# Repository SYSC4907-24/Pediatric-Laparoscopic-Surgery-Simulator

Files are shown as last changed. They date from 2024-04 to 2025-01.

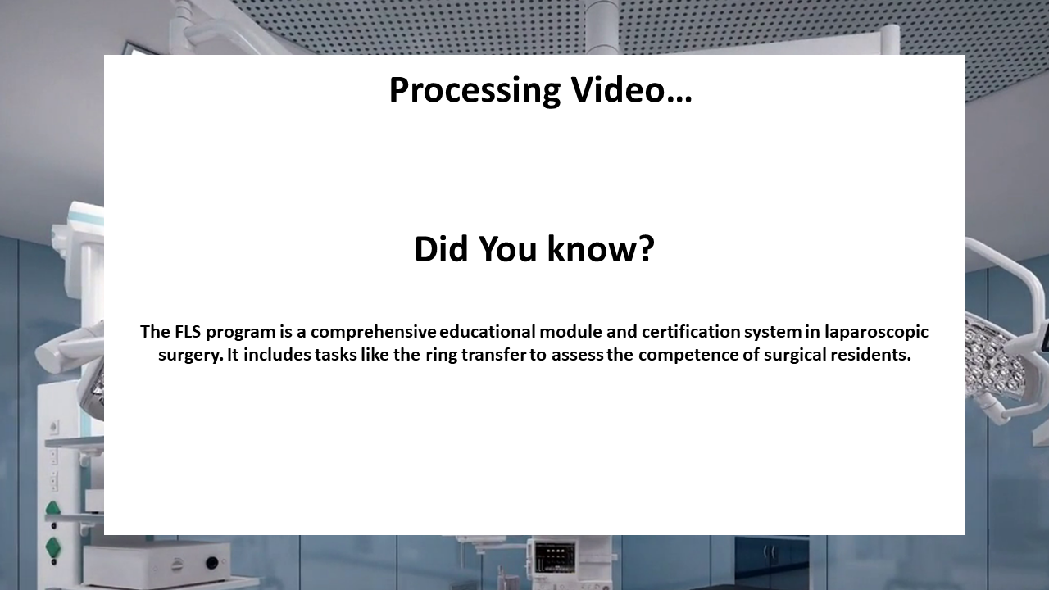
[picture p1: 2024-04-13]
Software/Slide8.PNG

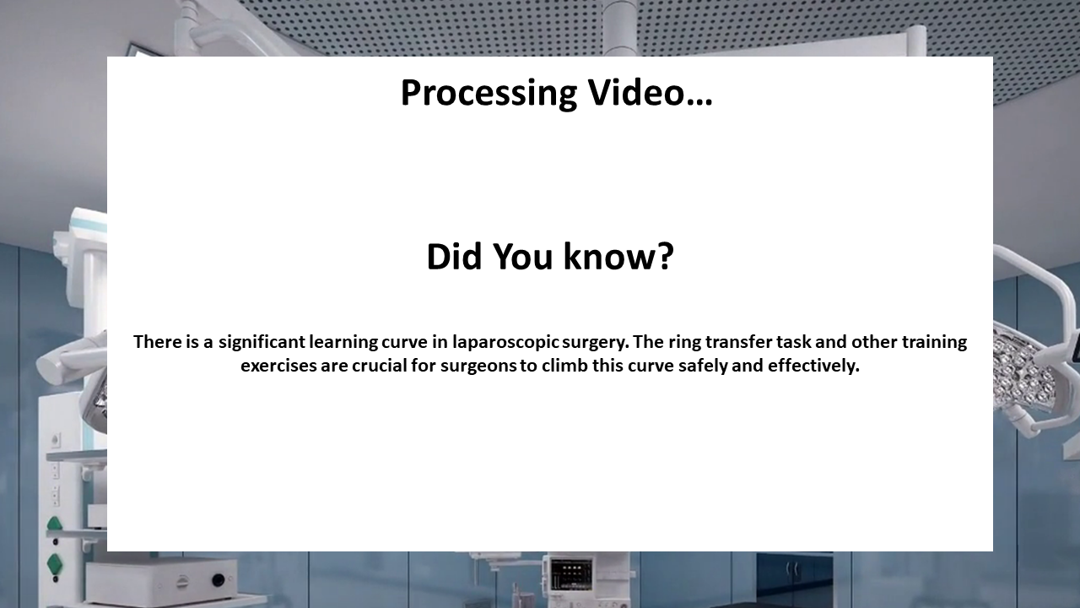
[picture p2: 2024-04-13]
Software/Slide6.PNG

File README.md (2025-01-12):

# Development of a Pediatric Laparoscopic Training and Skills Assessment Simulator 
*Source Repository for Systems and Computer Engineering Capstone Poject 2023 - 2024 at Carleton University.*

## Features
This project is a simulation designed for pediatric laparoscopic surgery training. The software simulates various surgical tasks, such as ring and suturing tasks. It captures video input, processes the data, and provides real-time feedback based on sensor data.

## Installation
### Requirements
* [Python 3](https://www.python.org/) (Tested on 3.7, 3.8)
* [Arduino](https://www.arduino.cc/en/software)
  * Set the loader to oldboot.

### Run Locally
Clone the project:
```bash 
  git clone https://github.com/SYSC4907-24/Pediatric-Laparoscopic-Surgery-Simulator.git
```
Install Python packages:
```bash
python -m pip install -r requirements.txt
```

Execute the `main.py` file:
```bash
python main.py
```

## Authors  
- Atallah Madi  
- Esraa Alaa Aldeen  
- Huda Sheikh 
- Youssef Megahed

If you have any feedback, please reach out to us.

Edit date: April 25, 2024.

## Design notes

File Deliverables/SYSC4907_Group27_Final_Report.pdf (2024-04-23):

Final Report

# Development of a Pediatric Laparoscopic

# Training and Skills Assessment Simulator

Authors:

Atallah Madi

Esraa Alaa Aldeen

Huda Sheikh

Youssef Megahed

Group 27

(Biomedical and Electrical Engineering)

Supervised by:

Dr. Carlos Rossa

Report Date:
April 10th, 2024

SYSC 4907

Department of Systems and Computer Engineering

Faculty of Engineering and Design

Carleton University

Final Report | Group Number: 27

II

Abstract

Pediatric laparoscopic surgery is a minimally invasive technique used for training trainees

on basic surgical movements while providing them with comprehensive feedback. The simulator

incorporates advanced technologies such as augmented reality (AR), sensor technology, signal

processing, and machine learning to provide an efficient learning experience that mimics a

complex pediatric laparoscopic environment. It addresses challenges such as operating in 3D while

viewing in 2D, enhancing learning, and eliminating expert supervision. This simulator's unique

features include real-time feedback and performance assessment through Dynamic Time Warping

(DTW) and deep learning, allowing for comparison with expert surgeons. The simulator is

designed to be user-friendly, with an intuitive UI and data processing pipeline, making surgical

training more accessible and efficient.

Keywords: Pediatric Laparoscopic, Simulator, Augmented Reality, Machine Learning, Deep

Learning, Surgical Gestures, Instrumentation, Feedback.

III

Acknowledgements

Group 27, comprising Atallah Madi, Esraa Alaa Aldeen, Huda Sheikh, and Youssef

Megahed would like to extend our sincere thanks to Dr. Carlos Rossa for his invaluable

mentorship, and remarkable support throughout our capstone project. We would also like to

acknowledge Dr. James Green for his constructive advice and practical suggestions, Dr. Ahmed

Nasr from C.H.E.O, and Dr. Georges Azzie from SickKids for their medical insights prior to our

development of the Pediatric Laparoscopic Surgery Simulator.

We would also like to express our appreciation to Carleton University for publishing an

article featuring our project, Biomechatronic Lab for providing us with the necessary tools and

working environment, the Systems and Computer Engineering Department and Kostiuk

Engineering Funding Collective for their generous funding, which made this project possible.

All these individuals and organizations have been instrumental in our project's success, and

we are deeply thankful for everyone and their contributions.

IV

Table of Contents

ABSTRACT | II
ACKNOWLEDGEMENTS | III
TABLE OF CONTENTS | IV
TABLE OF FIGURES | V
LIST OF TABLES | VII

V

Table of Figures

FIGURE 2: PEDIATRIC LAPAROSCOPIC SURGERY SETUP WITH A LAPAROSCOPE AND INSTRUMENTS INSERTED THROUGH TROCARS

FIGURE 3: LAPAROSCOPIC INSTRUMENTS COMMONLY USED TODAY. FROM LEFT TO RIGHT, LAPAROSCOPE (TOP LEFT), NEEDLE

FIGURE 4:THE FOUR DEGREES OF MOTION SURGEONS ARE LIMITED TO IN LAPAROSCOPY ARE THE ROLL, PITCH, YAW, AND SURGE

FIGURE 10:(A): ILLUSTRATION OF THE REFLECTION AND IMAGING SENSOR.(B): WORKING PRINCIPLE OF THE OPTICAL SENSOR

FIGURE 21: COMPARATIVE ANALYSIS OF AUTOMATED ACCURATE GESTURE DETECTION: SSD MOBILENET V2 320X320 VS.

FIGURE 22: COMPARATIVE OF AUTOMATED ACCURATE GESTURE DETECTION ON THE RIGHT (IMAGE C) AND INACCURATE ON

FIGURE 37: SAMPLE PROTOTYPE FOR OUR USER INTERFACE SHOWING VARIOUS MENU SCREENS (TOP) AND LOADING SCREENS

FIGURE 38: DESIGN FLOW OF NEW USER INTERFACE SHOWN WITH WINDOWS/SCREENS THAT APPEAR WHEN CERTAIN BUTTONS

VI

FIGURE 47: YAW (DEGREES) VS TIME (SECONDS) TEST WITH MPU INSIDE SENSOR HOUSING ON BOX [23] | 74
FIGURE 48: ROLL (DEGREE) VS TIME (SECONDS) TEST DONE WITH THE TOOL SHAFT INSIDE THE SENSOR HOUSING[23] | 75
FIGURE 49: SURGE (MM) VS TIME (SECONDS) WITH THE TOOL SHAFT INSIDE THE SENSOR HOUSING [23] | 75

VII

List of Tables

### 1. Introduction

This report provides a final update on our capstone project, a state-of-the-art Pediatric

Laparoscopic Surgery Simulator. This simulator, which incorporates advanced augmented reality

technology with machine learning, aims to provide enhanced feedback for performance evaluation.

Along with improved evaluation schemes, users are immersed in an interactive, risk-free training

environment that verbally and visually guides them throughout their learning experience. From

previous iterations, we have now integrated our machine-learning-driven object detection for

surgical tasks to be used for performance evaluation in real-time as the user interacts with the user

interface. We have also improved the hardware configuration of the simulator, equipping it with a

computer and display screen to ensure it is a compact, portable device that can be utilized in various

settings. Finally, significant improvements were made to enhance the user’s experience while

interacting with the user interface and viewing their feedback after performing a surgical task. The

changes implemented in this iteration will be detailed in the sections below. This report begins

with an overview of the project's primary goal, emphasizing the critical need for innovative

training tools in this specialized field of laparoscopic surgery. We then offer in-depth background

information crucial to understanding the project and the work we have accomplished this year.

This includes an overview of pediatric laparoscopic surgery, the current standards and

requirements for pediatric laparoscopic surgical training, and an analysis of recent technological

advancements in simulation tools that enhance the skill set of surgeons. In the following section,

we delve into the relevance of this project to the academic pursuits of each team member within

the fields of Biomedical and Electrical Engineering, outlining the specific responsibilities and roles

undertaken by each member during the project. The Implementation section will cover the four

areas of our project, namely the Hardware Instrumentation, Surgical Gesture Recognition, Data

Processing & Performance Evaluation, and User Interface sections. The Testing section will

provide a general overview of how we conducted multiple tests to ensure the functionality of our

instrumentation and software setup. Next, the Discussion and Analysis section will discuss some

general problems we encountered and how we resolved them. This section follows with the Future

Improvements section, which provides future capstone groups with suggestions on how the

simulator can be developed in later stages. Finally, to conclude, we discuss the benefits of the

innovative simulator we have created.

### 2. Background

Laparoscopic surgery, often called ‘keyhole’ surgery, is a minimally invasive surgical

(MIS) technique that differs from traditional ‘open surgery.’ Instead of making a large incision on

a patient’s abdomen, laparoscopy involves several smaller, 0.5-1 cm diameter incisions, each

called a ‘port’ [1]. A trocar placed inside a hollow sleeve or cannula at each incision or port is

slipped through to create an access point for surgery [2]. A trocar is a pen-shaped instrument

(triangular at one end) placed inside a hollow tubular instrument [2]. An image of a trocar is shown

below in Figure 1.

Figure 1 : Image of a trocar.[2]

In these incisions, the laparoscopic tools, a tube to pump gas into the abdominal cavity,

and a specialized camera called a laparoscope are placed through [3]. A sample placement of these

trocars is shown in Figure 2 below.

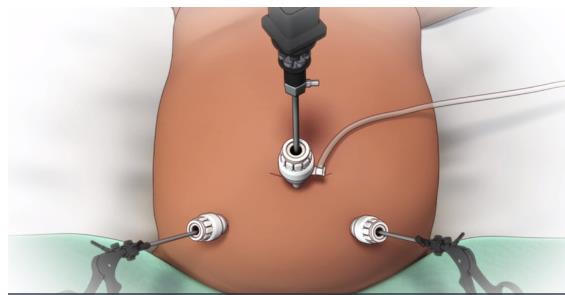
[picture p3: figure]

Figure 2: Pediatric laparoscopic surgery setup with a laparoscope and instruments inserted through trocars [3]

Various laparoscopic instruments available today are made of durable stainless-steel

material with narrow shafts up to 3-5mm diameter to fit through the ports [2]. Along with a

laparoscope, which is a thin telescope equipped with a camera and light source, there are a variety

of other tools available for various functions [2]. Needle drivers, composed of handles, joints, and

jaws, grasp suturing needles while securing wounds and surgical incisions [2]. Their tips may be

curved or straight [2]. Bowel graspers, 3 - 5 mm in diameter, handle, and grasp tissue, allowing

surgeons to observe and perform various procedures [2]. Other instruments used in laparoscopy

include scissors, suturing needles, and surgical meshes [2]. An image of these tools is given in

Figure 3 below.

Figure 3: Laparoscopic instruments commonly used today. From left to right, laparoscope (top left), needle grasper (top right), bowel grasper (bottom left), and surgical mesh (bottom right) [2]

Additionally, in laparoscopy, surgeons are limited to four degrees of freedom of motion,

which are the yaw, pitch, (counterclockwise/clockwise) roll, and (forward/backward) surge

movements [4]. They lose the heave and sway motions due to the pivots that hold the instruments

in place [4].

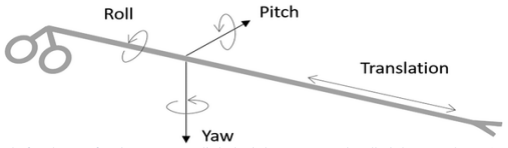
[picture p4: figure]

Figure 4:The four degrees of motion surgeons are limited to in laparoscopy are the roll, pitch, yaw, and surge (translation) movements [4]

Regarding postoperative outcomes, due to smaller incisions, laparoscopy is associated with

reduced pain post-operation, reduced scarring, reduced hospital stays, and lower incidences of

significant wound complications [5]. That means patients can return to everyday life and engage

in normal activities much sooner after their operation than open-surgery patients [5].

However, laparoscopy is known to have a steeper learning curve for trainees than

conventional open surgery, and each patient-specific procedure can present additional

complications for surgeons and trainees [6]. Thus, training for laparoscopy is different from

conventional open surgery training in several ways. Trainees must work within restricted spaces

and exercise less intuitive and limited movement through the trocars [7]. They must also enhance

their hand-eye coordination capabilities due to the added challenges of operating while looking at

a screen instead of operating under direct vision, like in open surgery [7]. There is also an increased

need to develop manual dexterity skills, like fine motor skills, since the long instruments used in

laparoscopy amplify even small movements and errors made by the trainee [7]. Trainees also

experience the fulcrum effect, which describes the inversion of movement while operating [7]. For

instance, this refers to when the surgeon moves their hand to the right, and the instrument's tooltip

is moved to the patient's left on the screen [7].

Additionally, trainees have to grapple with challenges like only using four out of six

degrees of motion, the lack of physical sensation or touch from their hands, and the lack of 3-

dimensional images like in open surgery [7]. In a clinical setting, laparoscopic training can largely

depend on the variety of cases that arrive at the hospital [6]. Due to the increased need for the

unique skills required for laparoscopy, a need arose to develop relevant simulators and training

programs. Simulators provide trainees with a safe, ethical, and friendly learning environment to develop their hand-eye coordination abilities, improve their manual dexterity, and soften the

learning curve of acquiring laparoscopic skills [6].

When minimally invasive surgery (MIS) was first adapted for infants and children, training

surgeons and residents on pediatric laparoscopy presented additional challenges [8]. The use of

smaller workspaces, shorter and narrower instruments, smaller margins of error, and the expansion

of MIS in children and infants warranted the development of specific learning approaches and

simulators for pediatric laparoscopy [8]. This type of procedure demands a more unique set of

operating skills than adult laparoscopy. The abdomens of children and infants present a small

workspace whereby damage to nearby vessels, the bowel, and other structures can quickly occur

and lead to grave consequences [9]. While the instruments are smaller and narrower, surgeons

must still maneuver these within smaller anatomical structures and a restricted operating field

[9,10]. Due to these limitations, there also exists a lower tolerance of forces to surrounding tissues

[10]. Thus, the demand for the unique skill set to perform the procedure has led to the use and

development of pediatric laparoscopic simulators. These simulators must mimic the challenging

surgical environments in their setup by using smaller instruments, smaller needles, more sensitive

force-sensing devices, and more limited surface areas for training tasks [10].

The Fundamentals of Laparoscopic Surgery (FLS) was a program developed by the Society

of American Gastrointestinal and Endoscopic Surgeons (SAGES) in 2004 to develop a framework

that assesses knowledge and skills acquisition for laparoscopic surgery [11]. The program has been

widely regarded as a valid and reliable tool and educational curriculum to train and assess surgeons

[11]. The Canadian Association of General Surgeons endorses the FLS program as a valuable and

comprehensive training and assessment tool to gauge residents’ knowledge and skills in basic

laparoscopic training. The FLS examination consists of a web-based cognitive examination, followed by a manual-skills assessment on five fundamental laparoscopic tasks, namely, the peg

transfer task, precision cutting task, ligating loop task, suturing with extracorporeal knot-tying

task, and suturing with intracorporeal knot-tying task [11]. For now, and for our group’s proposed

surgical simulator, the focus will be on the peg transfer task and the suturing tasks with

extracorporeal knot-tying and intracorporeal knot-tying [11]. More tasks may be added to our

simulator if time, resources, and efforts allow.

The most straightforward task, the peg transfer task, involves using two Maryland grasper

dissectors [12]. It gets trainees to grasp each ring with their non-dominant hand one by one and

transfer it to their dominant hand in mid-air to place it on a peg on the opposite side of the board

[12]. The process is repeated until all rings are on the other side of the board [12]. This process is

then repeated in reverse, starting with the dominant hand and then transferring the rings to the non-

dominant hand [12]. Penalties are applied if the ring falls out of the field of view or is no longer

retrievable, but trainees are still expected to continue the procedure should this happen [12]. If a

ring is dropped within the field of view, trainees can pick it up with their hands and continue the

procedure [12]. The FLS recommends that trainees complete this entire procedure in 300 seconds,

with the time starting from the minute the grasper touches the first ring till the time the grasper lets

go of the last ring [12].

In the extracorporeal suturing task, trainees are expected to use two needle drivers (or one

Maryland grasper and one needle driver) and endoscopic scissors to place a long suture through

two marks in a Penrose drain and then perform three single throw knots (extracorporeally) to

secure the slit on the drain [12]. Then, once the three throws are secured, both ends of the suture

are cut [12]. Penalties are applied for a knot that falls apart, for deviating from the suturing marks

on the Penrose drain, and for improper closure of the slit [12]. This procedure is expected to be completed within 420 seconds, beginning when the first tool is visible through the camera and

ending when the cuts are made to either end of the suture [12].

Similarly, in the intracorporeal suturing task, trainees are expected to use two needle

drivers (or one Maryland grasper and one needle driver) and endoscopic scissors to place a short

suture through two marks in a Penrose drain and then perform three throws of a knot (one double

throw, and two single throws) intracorporeally to secure the slit on the drain [12]. Then, once the

three throws are secured, both ends of the suture are cut [12]. Penalties are applied for a knot that

falls apart, for deviating from the suturing marks on the Penrose drain, and for improper closure

of the slit [12]. This procedure is expected to be completed within 600 seconds, beginning when

the first tool is visible through the camera and ending when the cuts are made to both ends of the

suture [12]. While a scoring rubric from the FLS is not publicly available, plenty of scoring

methodologies developed by medical professionals exist online. They can be used to assess the

performance of trainees. For instance, many experts have developed independent scoring rubrics

for the five basic laparoscopic tasks [13].

To adapt the FLS training and assessment framework for pediatric laparoscopy, smaller

and softer rings for the peg transfer task, as well as the 3 mm graspers instead of the 5 mm ones

used for adult laparoscopy, should be employed [10]. The size of the Penrose drain used in the

intracorporeal, and extracorporeal suturing tasks should be reduced by 6, and smaller needles and

3 mm instruments should be used [10]. Additionally, the surface area of the Velcro securing the

drain to the board should be decreased by a factor of 5 to increase the risk of avulsion that can

occur due to the application of even minimal force in pediatric laparoscopy [10]. The timing and

penalty scores could be the same as that for adults, except additional parameters or penalties may need to be added to the scoring rubric for pediatric laparoscopies, such as assigning the trainee a

score of zero if avulsion of the Penrose drain occurs [10].

### 2.1. Description of Current Surgical Simulators

The advent of surgical simulators has opened a new avenue in surgical training. It provides

surgical residents and trainees with a safe, trainee-friendly learning environment to practice new

instruments, procedures, and skills before operating on actual patients [1]. Due to the rapidly

changing nature of instruments and laparoscopy’s less intuitive techniques/procedures, it is

difficult to use the traditional apprentice approach when teaching laparoscopic skills to novices

[1]. Thus, many surgical simulators have focused on developing simulation training for

laparoscopic surgery [1]. These have included low-tech and high-tech simulators like video-box

trainers, organic simulators (on human cadavers and animal models), hybrid trainers, virtual reality

(VR) trainers, and augmented reality (AR) simulators [14].

Video-box trainers resemble traditional box trainers in that they provide a box and holes

for trocar insertion and various laparoscopic tasks, but also a camera projected on a monitor for

the trainee [14]. While they can help practice hand-eye coordination skills and particular

laparoscopic tasks, they need more objective expert feedback and focus only on specific

tasks/techniques rather than an entire procedure [14]. They require the presence of an expert to

assess the performance of a trainee, which is only sometimes available. The FLS uses the McGill

Inanimate System for Training and Evaluation of Laparoscopic Skills (MISTELS) system to train

novices on the five core laparoscopic tasks as part of its laparoscopic training program [14].

Hybrid trainers, or virtual reality (VR) trainers, integrate video-box simulators with virtual

reality to guide a trainee throughout a performance with interactive haptic feedback and feedback

metrics without needing an expert surgeon to be present [14]. The user can practice individual skills like suturing, knot-tying, etc. or go through an entire procedure in a realistic computer-

generated environment in more advanced simulators [14]. Objective feedback can be in the form

of time taken for a particular procedure or the strength of a knot [14]. Several VR trainers for

different subspecialties have become available, including LapSim and Lapmentor simulators for

laparoscopy [14]. Sometimes, these simulators may require additional time and effort to set up and

maintain as they are not portable. However, they train residents to make sound decisions, preparing

them for intense operating environments [14].

Finally, augmented reality (AR) trainers, which overlay computer-generated information

into the user’s field of view, connect the virtual world to the real world [14]. Some of the

approaches covered by AR simulators include overlaying computer graphics on anatomical

structures, mapping instrument paths during a procedure, creating a realistic training environment

that involves real instruments interacting with actual artifacts in the surgical environment, and

providing objective force, motion, and haptic feedback without the need of an expert observing

the performance in real-time [14].

The current implementation of our Pediatric Laparoscopic Surgical Simulator project is an

augmented reality (AR) simulator, overlaying the surgical environment in the box trainer with

computer-generated information to guide the user through a laparoscopic task, like the peg transfer

task. Currently, thresholds from sensory information regarding force, velocity, and acceleration of

movement are used to assess trainee performance. Our current focus is to enhance the AR simulator

by adding more advanced laparoscopic tasks and integrating it with powerful machine learning/

signal processing algorithms and an interactive user interface to enable it to recognize surgical

gestures and classify a user’s performance based on accurately collected expert data.

### 2.2. Machine Learning and Surgical Simulation

Current literature on laparoscopic surgical simulators has focused on applying artificial

intelligence (AI) to surgical simulators. AI aims to mimic human intelligence by learning to

predict, classify, and learn a particular task to make decisions [15]. AI can enhance surgical

simulators today by assessing a trainee's performance, providing more personalized feedback, and

enhancing the visualization of the surgical environment itself [15]. Among high costs and long-

term maintenance, current VR simulators like LapSim and AR simulators like ProMIS present

other limitations, like insufficient metrics/performance criteria to assess trainees [16]. For instance,

the ProMIS AR laparoscopic simulator uses "time of performance," "path length," and

"smoothness of motion" to assess trainee performance [16].

On the other hand, the LapSim simulator uses "time of performance," "tissue damage," and

"path length" to assess trainee performance [16]. "Time of performance" cannot be the most

important criterion with which to assess trainees, especially since the primary area of concern is

often whether the trainee has used the correct technique and tied a knot properly [16]. Most current

simulators do not accurately assess specific surgical techniques, compare a trainee's performance

to an expert's performance and provide constructive feedback that the user can understand or

implement [17]. Instead, they assume agreed-upon minimum threshold values for completion time,

path length, collisions, force, or velocity to assess a user's performance [17].

Machine learning can evaluate performance more accurately and provide more

personalized feedback to the user. For instance, machine learning algorithms can be trained to

recognize patterns of movement and behaviour in novice and expert performers to provide more

detailed feedback to the user. In this way, incorporating machine learning into our simulator will

provide more instructional and informative feedback to the user, increasing the educational value

and usefulness of the simulator itself.

There have been several AI-related applications in surgical simulators in recent years [15].

A group at McGill University developed a machine learning algorithm that classified the skill

levels of surgeons during a brain tumour resection task and provided detailed feedback [15]. This

was done by getting machine learning algorithms to select important performance metrics from an

expert-defined list and use these to distinguish between the skill levels of surgeons in a virtual

reality simulator [15]. The algorithms could select a novel list of performance metrics and achieve

high classification accuracies when classifying trainee performances along training levels [15].

However, the challenges and problems introduced by applying AI and machine learning to surgical

simulation training must be addressed. For one, the lack of valid and objective performance metrics

for an algorithm to use, and another, the inability of the algorithm to accurately correlate between

a trainee's performance on a simulator and in the operating room [15]. In addition, these algorithms

may not consider the variety of methods and techniques trainees can use to achieve a particular

goal. Potential solutions to these problems could be to divide a procedure into sub-tasks and obtain

surgeon-led consensus on evaluation metrics in laparoscopy.

We aim to integrate our current AR pediatric laparoscopic surgical simulator with machine

learning and signal processing algorithms to 1) classify individual gestures or sub-tasks within a

surgical procedure (like the peg transfer and suturing tasks) and 2) evaluate a trainee's performance

and compare them to an expert's performance. Our conversation with pediatric surgeons Dr.

Ahmed Nasr and Dr. Georges Azzie on September 27th, 2023, focused on how the machine

learning algorithms that we will develop can assess a trainee's success in completing each sub-task

of a procedure by evaluating their smoothness of movement, patterns of motion, and application

of force. Each trainee's performance will be compared against the performances of actual, standard,

expert data we have collected.

### 3. Project Objective

The objective of this project was to develop a portable, easy-to-use, cost-effective, and

user-friendly simulator for pediatric laparoscopic surgery that would provide trainees with

comprehensive feedback about their performance without the need for constant expert supervision.

The objective was to design the simulator to evaluate the performance of trainees after they

complete the assigned task and provide them with various types of feedback, they can

independently use to assess their skills. We designed the simulator to compare the trainee’s

performance against an expert’s to easily see where they may have erred. This comparison formed

the basis for the various types of feedback we intended to provide in the form of graphs, videos,

and maps of tool trajectories. In addition to the comprehensive feedback and evaluation measures,

we used an existing version of the simulator. We equipped the simulator with additional

instrumentation to measure motion and force-related parameters. We also designed the box

simulator to be a more portable, compact, and easy-to-use device. Finally, to connect all the

components, we consolidated everyone’s parts together and integrated them with a more powerful

and interactive user interface. The major functional parts of this project included equipping the

simulator with the appropriate instrumentation to ensure accurate performance capture, gathering

performance data from these sensors, analyzing the gestures of a trainee’s performance, processing

all this data to compare with an expert’s performance, and providing users with an interactive user

interface that they can use to view different types of feedback. Over the past months, we have

developed a simulator compact and powerful.

### 4. Relation to Studies

Now that the project has been completed for the 2023-24 year, it is essential to reflect on

the relevance and importance of this project to our academic studies and how it has deepened our

understanding in our respective areas.

All members of the team - Atallah, Esraa, Huda, and Youssef - are currently in their final

year of their undergraduate degree program in Biomedical and Electrical Engineering. The degree

has equipped them with a shared foundational knowledge and skill set essential for their

collaborative effort. While each member brought unique strengths and expertise to the project,

they all shared a solid academic background, ensuring their overall project contributions aligned

with their studies and objectives.

Atallah’s academic journey has given him a deep understanding of project design,

biomedical instrumentation, digital and analog electrical circuits, and various programming

languages. All these fundamental concepts came together to build his role in the project, where he

focused on enhancing the platform design, upgrading its instrumentation, and creating the system

data pipelines. His academic background in hardware, software, and electrical equipped him with

skills essential to the project. His introductory engineering course in his first year laid the

groundwork for designing an innovative platform, employing CAD models, and developing a new,

portable screen mount. Furthermore, his co-op position as a hardware developer was instrumental,

providing him with the practical experience necessary to upgrade the force sensors and resolve

various sensor-capturing discrepancies. With his improvements, Atallah has ensured that data are

captured with enhanced accuracy, and the simulator now boasts portability, allowing for a broader

range of training scenarios and environments. These advancements mark a significant leap forward

in surgical education, making training more accessible and practical.

Esraa leveraged her academic knowledge to refine her skills and capability, significantly

contributing to the gesture recognition component of laparoscopic tasks. Her work was realized

through deep learning and convolutional networks, which were adept at extracting robust features

from real-time data. This extraction facilitated the provision of varied guidance tailored to the

object states during training. Furthermore, she automated the labour-intensive task of labelling

surgical gestures. Utilizing a deep learning model, she enabled automatic labelling of user/trainee

gestures alongside their respective timestamps. This process constituted a crucial preprocessing

step later integrated into our pipeline for thorough performance evaluation.

Huda, throughout her degree and her coursework, has worked on several projects related

to biomedical engineering in academics, research, and industry. Throughout these projects, she has

gained experience in image processing, biomedical imaging, sensor analysis, software

development, and project management. Huda’s primary goal in this project consisted of

consolidating the project's signal processing and machine learning aspects (the performance

assessment and gesture recognition algorithms) with a powerful, interactive user interface (UI)

that guides and assesses a trainee throughout their performance. This ensured that the laparoscopic

surgical simulator functioned correctly to present the user interactive feedback, as the performance

assessment and gesture recognition algorithms provide.

Youssef's degree provided him with comprehensive exposure to hardware and software

development, signal processing, machine learning, and biomedical engineering knowledge.

Beyond academic studies, Youssef gained hands-on experience in medical imaging research,

where he harnessed the capabilities of deep learning. Additionally, as a data science intern, he

honed his skills, adeptly using machine learning and Python. His primary focus was signal

processing and evaluating user performance using techniques such as Dynamic Time Warping.

For the project, Youssef developed a robust signal-processing algorithm that delivers feedback to

the user through videos, graphs, and tool trajectory maps. This algorithm processes simulation data

to assess trainee performance accurately. Additionally, he applied machine learning to develop an

LLM-based chatbot, enabling users to ask questions about surgical training. This chatbot is based

on the GPT-3.5 Turbo model. Youssef also took on the task of cleansing and standardizing raw

sensor data, organizing it into structured data frames, and saving it as CSV files. This prepared

data feeds into evaluation algorithms, providing valuable insights into trainee performance.

Throughout his studies and professional experiences, Youssef's diverse techniques and methods

have laid the groundwork for his contributions, ensuring that users of the training simulator receive

clear and precise results.

### 5. Contributions

### 5.1. Project Individual Contributions

Table 1: Outline of each member's contribution to the capstone project

Contributor | Section
Atallah Madi | • Hardware and sensor installation. • Sensor verification and calibration. • Schematics, electrical wiring, and soldering. • CAD modelling and 3D printing. • Camera and HSV calibration. • Microcontroller program and data pipeline. • Participated in data collection.
Esraa Alaa Aldeen | • Gesture recognition modelling. • Data collection and labelling videos dataset. • Implementation SSD for gesture detection. • Developing a new improved model for gesture recognition. • Training and implementation the ST Model. • Models tuning and evaluation.
Huda Sheikh | • User Interface Design. • Assisted in UI Integration. • Software debugging, verification, and calibration. • Implementing tool trajectory feedback. • Camera and HSV calibration. • Participated in data collection for gesture recognition model. • Assisted in data labelling for gesture recognition model.
Youssef Megahed | • Assisted in sensor verification. • Data processing pipeline implementation. • Signal processing techniques implementation. • Software implementation of all the different types of feedback. • UI integration. • Assisted in software debugging and verification. • Participated in data collection for gesture recognition model. • Worked on the new gesture recognition model.

### 5.2. Report Individual Contributions

Table 2: Outline of each member's contribution to the final report

Contributor | Section
Atallah Madi | • Acknowledgement • Relation to Studies • Implementation (Embedded system) • Testing • Discussion and Analysis • GitHub repository
Esraa Alaa Aldeen | • Abstract • Relation to Studies • Implementation (Surgical Gesture Recognition)
Huda Sheikh | • Introduction • Background • Project Objective • Relation to Studies • Implementation (User Interface Design)
Youssef Megahed | • Introduction • Relation to Studies • Implementation (Data Processing Pipeline, Performance Evaluation, and Development and integration of new features in the user interface) • Testing • Discussion and Analysis • Future Improvements • Conclusion • GitHub repository

### 6. Implementation

### 6.1. Embedded system

### 6.1.1. Sensors and Microcontroller

The system incorporates two types of sensors, the MPU6050 and PMW3389, placed at the

trocars to capture the four movements: Roll, Surge, Pitch, and Yaw. Furthermore, the system’s

platform is instrumented by using load cells and HX711 (analog-to-digital convert and amplifier),

which captures the applied bidirectional forces.

All these hardware sensors require a microcontroller to operate and collect the data. Thus,

the use of an Arduino Nano board. It is equipped with digital (I2C and SPI) and analog

communication busses which the MPU6050, PMW3389, and force sensor use. The speed of

communication is uniform for all sensors at a 31250 baud rate which provides high-speed data

transmission. The entire project circuitry with all the used pins on the microcontroller and the data

pipeline are shown in Figures 5 and 6 receptively.

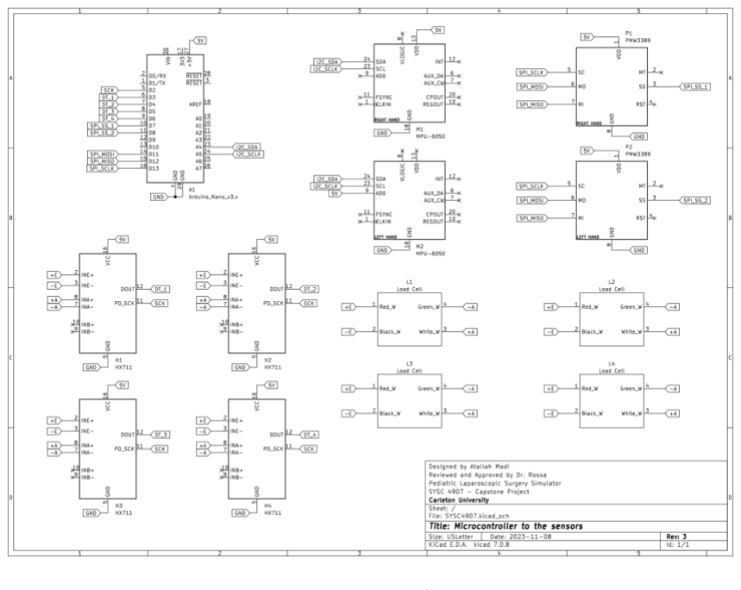
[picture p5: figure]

Figure 5: Project schematic

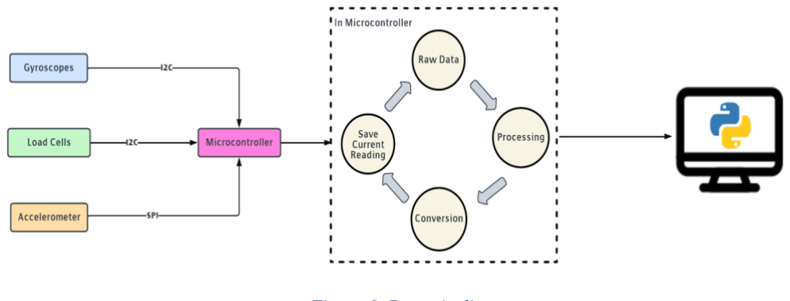
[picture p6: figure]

Figure 6: Data pipeline.

I2C (Inter-Integrated Circuit) is a two-wire communication protocol widely used for

connecting various peripheral devices to microcontrollers, such as Arduino boards. Each I2C

sensor requires two essential lines: SDA (Serial Data) and SCL (Clock Line), to establish the

connection [18]. The SDA line is used for bidirectional data transfer between the Arduino and the

sensor, allowing them to exchange information. Meanwhile, the SCL line carries clock signals

generated by the Arduino, synchronizing the timing of data transmission between devices.

Together, these two lines enable efficient and synchronous communication between the Arduino

and multiple I2C sensors (MPU6050, and HX711) connected on the same bus.

Figure 7: I2C Bus circuitry [18].

SPI (Serial Peripheral Interface) is a synchronous serial communication protocol

commonly used for short-distance communication between microcontrollers and peripheral

devices. Unlike I2C, SPI typically requires four communication lines: MOSI (Master Out Slave

In), MISO (Master In Slave Out), SCK (Serial Clock), and SS (Slave Select). MOSI is used by the master device to send data to the slave device, while MISO is used in the opposite direction [19].

SCK generates the clock signal, synchronizing data transfer between the master and slave devices.

The SS line allows the master device to select the specific slave sensor (PMW3389) with which it

wants to communicate. SPI operates in full-duplex mode, meaning data can be transmitted and

received simultaneously, providing faster communication compared to I2C [19].

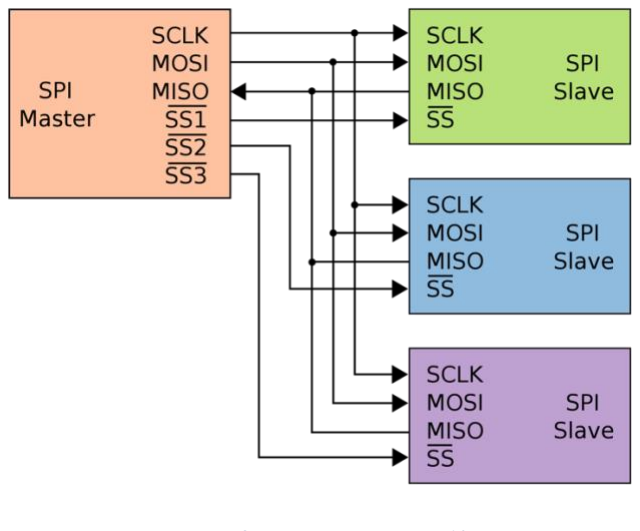
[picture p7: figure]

Figure 8: SPI Bus circuitry [19].

The MPU6050 sensor is a six-axis motion-tracking module that combines a 3-axis

gyroscope and a 3-axis accelerometer [20]. This sensor captures pitch, and yaw movements by

measuring angular velocity and linear acceleration along each axis. The gyroscopic component

accurately detects rotational movements, while the accelerometer provides orientation and tilt

information.

Figure 9: MPU6050 three-dimensional axis [20].

The PMW3389 sensor is primarily utilized for precise tracking of linear movements and

rotation, making it ideal for detecting surge (linear movements) and roll (rotational movements).

It uses optical motion technology which is commonly found in applications such as computer mice

and robotics. The sensor resolution is 16,000 CPI (Counts Per Inch) which refers to the number of

digital counts the sensor reports for every inch the surface moves on over it [21]. The reading is

captured by infrared light that reflects off to the image sensor which takes continuous snapshots

of the surface and compares the images to determine the distance and direction of travelling in X

and Y direction [21].

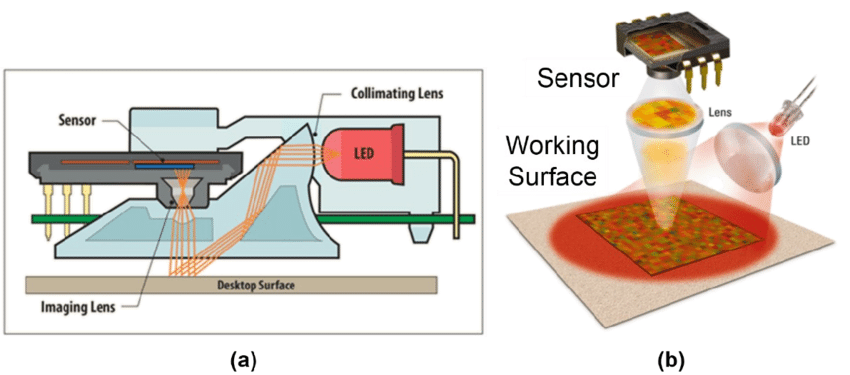
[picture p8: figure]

Figure 10: (a): Illustration of the reflection and imaging sensor. (b): Working principle of the optical sensor [22].

To determine surge, the CPI value in the Y displacement must be converted into mm. The

sensor outputs the CPI value in two’s complement format (for negative displacement) using 32,767

bits to represent 16,000 different CPI values. Since CPI is in inches it must be converted to mm (1

inch = 25.4 mm) resulting in using 1290 bits for 1mm. This conversion is implemented in the code

using equation 1 with the corresponding data variable (data.1.dy and data2.dy) for left and right

respectively [23].

Surg (mm) = L_PMW_Y =

data1.dy
1290.0
+ L_PMW_Y | (1)

To determine roll, the CPI value in the X displacement must be converted into mm which

is similar to the surge movement. However, since the sensor reads the shaft's movements from an external view, where it is placed on the tool shaft. The degree of rotational roll could be calculated

by using the arc length equation with the tool shaft radius (r =1.5mm). This conversion is

implemented in the code using equation 2 with the corresponding data variable (data.1.dx and

data2.dx) for left and right respectively [23].

Arclengtℎ

(mm) = L_PMW_Y =

data1.dy
1290.0

+ L_PMW_Y

Arclengtℎ

(mm) = L_PMW_Y = 2π × r × (

θroll
360∘

)

θroll = 360∘ ×

L_PMW_Y
2π×1.5mm

(2)

The load cell employs strain gauges and the HX711 amplifier to measure both compression

and tension forces, enabling measurements in both upward and downward directions. When a force

is applied, whether pushing down (compression) or pulling up (tension), the strain gauges deform,

altering their electrical resistance utilizing the Wheatstone bridge circuit [24]. This change in

resistance is amplified and translated into a voltage signal by HX711, providing a precise

indication of the applied force. There are four different bar load cells each capable of measuring

up to 1 kilogram, equivalent to 9.81 newtons, mounted on the platform.

During the calibration process, the readings from all the load cells are collectively treated

as one, as they are calibrated to measure the reference weight as a single unit rather than individual

readings to be averaged. This unified approach ensures consistency and accuracy across all load

cells, aligning their measurements with the predetermined reference weight.

Figure 11:Load cells equivalent circuit [24]

### 6.1.2. Peripherals

In the setup, the main camera view is captured by a higher-resolution camera with 2K

resolution (2560 x 1440) at 30 FPS (frame per second), providing sharper and more detailed

images. This camera is positioned atop the training box, and it is complemented by using white

LED lighting, ensuring optimal illumination for clear imaging. Additionally, a touchscreen

monitor, and computer are integrated into the setup as part of the user interface and compatibility.

The computer serves as the central processing unit for the system, and it is responsible for running

the main program, managing data flow, handling image processing tasks, and powering all the

hardware parts: monitor, microcontroller, camera, and LED light. Hence, achieving a portable,

compact system.

### 6.1.3. Computer-Aided Design (CAD) Models

Both the PMW3389 and MPU6050 sensors were installed within an enclosed unit

positioned atop the trocars. The housing unit and trocar were designed using Fusion 360 software.

The trocar itself features two rings to facilitate pitch and yaw movements while remaining securely

within the box. Moreover, a 3.4 mm-wide opening in the trocar ensures smooth tool insertion

without friction, enabling the PMW3389 sensor to track the tool shaft's movement and rotation.

For visual reference, the CAD models depicting the trocar design are provided in Figure 12. The

sensor housing is designed to allow mechanical protection for the sensors while also eliminating

light interference that could affect the optical sensor when detecting the tool shaft [23].

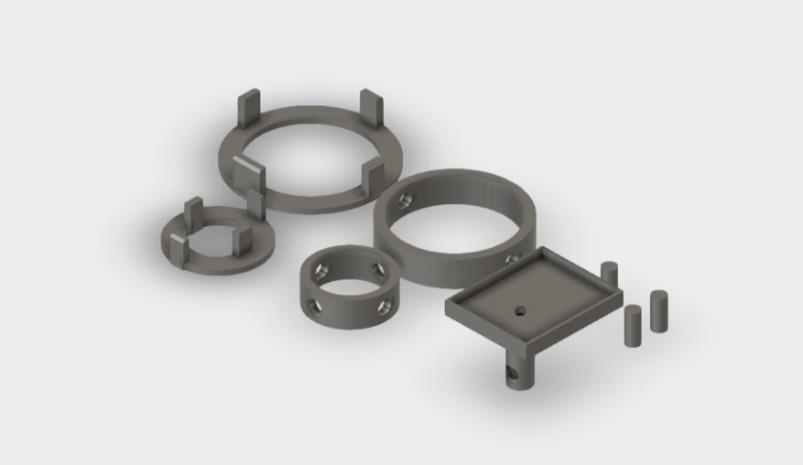
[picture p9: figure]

Figure 12: Trocar model the disassembled [23].

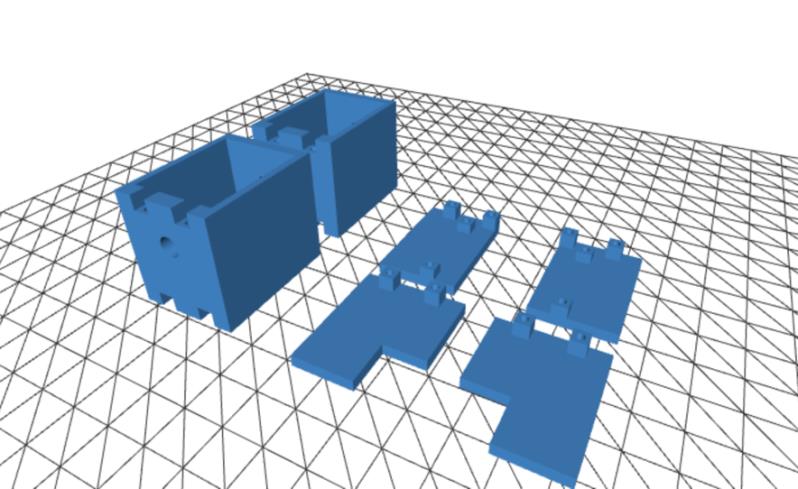
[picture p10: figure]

Figure 13:Housing units for the sensors disassembled [24].

The platform design is made of two plates with two main goals: smoothly adding new load

cells and addressing stability concerns. To make room for the new load cells, added spaces and

mounting points in the design. This ensures that the load cells are perfectly positioned for accurate

force measurements, with fixing points both upward and downward to align with any applied force

in those directions as shown in Figure 14.

Figure 14: Mounting position for one of the new load cells [25].

Integrating the new load cells also required us to include support structures, like additional

fixtures at the bottom plate, to secure and stabilize the amplifiers. These fixtures act as strong

supports for the amplifiers, preventing any unintended movements or vibrations that could affect

the accuracy of force readings.

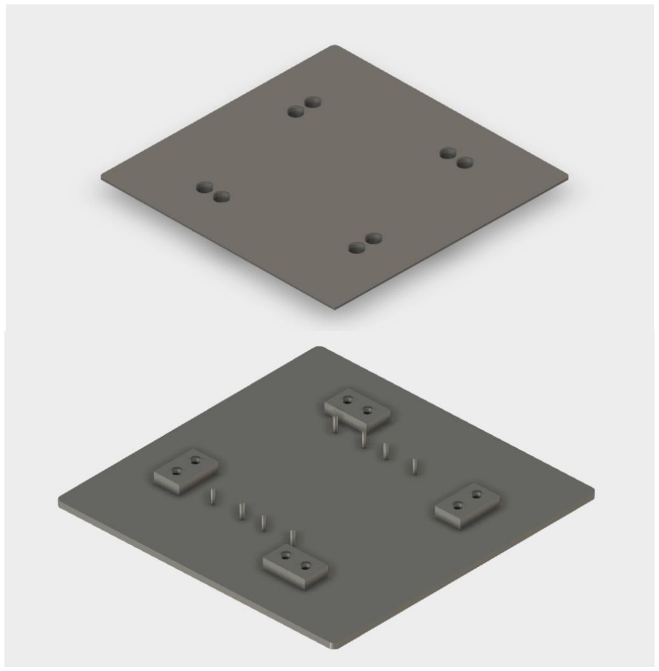
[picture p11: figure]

Figure 15: Top and base plates for the platform.

After soldering all sensors to a prototyping board. This prototyping board needed a housing

box along with the Arduino to both reduce exposure of the circuit and tidy up the workspace for

the user. The box contains a variety of entry and exit points for wires, as well as points to bolt the

prototyping board to the housing using M2 screws.

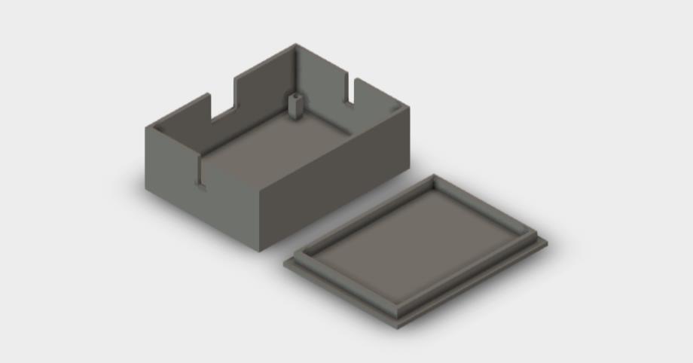
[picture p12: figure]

Figure 16: Housing unit for the microcontroller and the circuit.

The monitor has its components exposed therefore a case was necessary to cover them and

provide protection to the monitor. The case dimensions are larger than the 3D printer leading to

slicing the case in half to be able to print it and then glue them together using epoxy glue. In

addition, a screen holder and a mount were 3D printed along with other miscellaneous parts such

as cable management holders, and case fixtures which are provided in the project repository

(Appendix A).

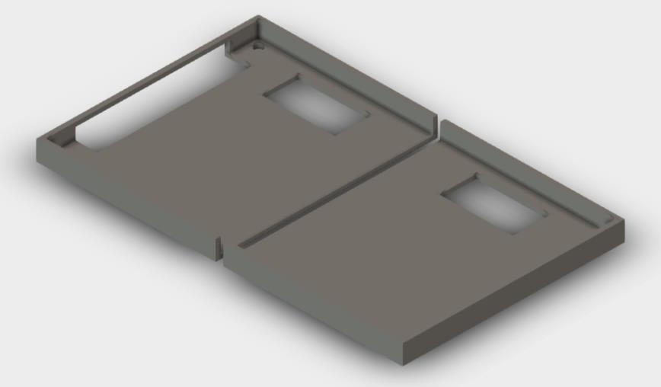
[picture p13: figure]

Figure 17:Screen case with holes for buttons and speakers.

### 6.2. Surgical Gesture Recognition

### 6.2.1. Task Description

Timely and accurate feedback is crucial for improving the efficacy of surgical training.

However, the traditional approach, which relies on manual evaluation for feedback, can be

subjective, inconsistent, and resource intensive. Additionally, manually labelling surgical gestures

in training videos for feedback purposes is time-consuming and prone to human error. This

limitation restricts delivering immediate, objective, and detailed performance analysis. The

reliance on manual approaches to evaluate surgical training activities poses a substantial barrier to

reaching the highest standards of surgical proficiency. This approach must be adjusted to maintain

training efficiency and feedback quality. There is a clear need for a technology-driven solution

that enhances the accuracy and reliability of performance assessments in surgical training by

streamlining the feedback mechanism.

The proposed solution is to automate the gesture labelling process using state-of-the-art

gesture recognition techniques. This automation aims to replace manual gesture labelling,

traditionally performed by experts, and then recorded in spreadsheets for analysis. The method

will specify, classify, and label different surgical gestures from training videos using deep

learning-based gesture recognition methods. This process improves precision and consistency in

gesture recognition and significantly reduces the time and effort involved in manual labelling.

To this end, our task is to develop an automated system using deep learning treal-

timeccurately recognize and label surgical gestures in real time. This system will analyze surgical

training videos, identify specific gestures, and label them without human intervention. Secondly,

automated labelling should be used to evaluate trainees and provide them instant feedback quickly

and objectively. The system will automatically analyze the trainees' performance, recognize their gestures, and automatically generate feedback information. This feedback will be systematically

recorded in a structured format, such as an Excel sheet, for easy access and analysis.

The two main objectives guided this task are:

- Developing gesture modelling specifically tailored for training tasks.
- Implementing a deep learning-based gesture recognition method in our surgical

simulator can support real-time applications.

Through this approach, the aim is not only to enhance the accuracy and efficiency of our

model but also to contribute innovative solutions in gesture detection and tracking to the more

comprehensive field of surgical training.

Figure 18: Gesture recognition pipeline.

### 6.2.1.1. Gesture Modelling

In creating the gesture model for the machine learning application, the focus was on

describing the critical elements required for the surgical training simulations, such as identifying

the left and right graspers and the rings and their various states and movements. To accomplish

this, we outlined two fundamental attributes for each of these gestures:

- Location: This attribute precisely describes the grasper's pixel coordinates in the simulation

to ensure proper spatial tracking.

- Movement: We recognized movement as an important relational attribute that captures the

interactions between objects, such as holding the ring together with the left grasper, which

indicates a movement of "Ring transfer. This attribute is required to recognize each action's

purpose and context within the simulation.

As described in Table 3, the gesture model demonstrates a comprehensive list of potential

movements and states. These include the idle state of the graspers (LG0 and RG0), various

activities towards and away from the operating table (e.g., LG1, RG1), and interactions with the

rings, such as clasping or transferring (e.g., LG3, RG6). This table provides a structured framework

for the gesture's potential movements and relations within the simulation. Further, we used a

semantic gesture model approach, which augments the essential attributes of location and

movement with their semantic implications. This increases the machine learning algorithm's ability

to study the activities within the simulation, moving beyond mere coordinate tracking to

understanding the semantic purpose of each movement. For instance, the semantic model allows

the algorithm to determine that "LG3'': Left pick ring: Clasping ring represents an action where

the left grasper picks and clasps the ring instead of identifying the spatial coordinates of the grasper

and ring. The semantic gesture model facilitates gesture state detection by focusing on location, making it more efficient. This approach allows our machine learning model to accurately track

location and analyze contextual relationships in surgical training simulations for real-time

feedback and assessment. Based on the description of Peg transfer task, an ideal performance

required the following sequence of gestures:

Peg Transfer: RG0→ RG1 → RG2 → RG3 → RG4 → RG5 → LG1 → RG6 → LG2 → RG7 →

LG3→ RG8→ LG4→LG5→LG6→LG7

Table 3: The Gestures Classification by Movement and Location.

Gesture Index

(Right) and

(L: Left)

Objects Movement

Jaws (Open

or Closed)

RG0 | Ring on peg: Idle state (or hovering) | C
RG1 | Right grasper: Moving vertically downwards towards peg on right side of operating table | O/C
RG2 | Ring out peg: Positioning ring between the jaws and clasping it | O
RG3 | Right pick ring: Moving upwards with clasped ring | O
RG4 | Right Carry ring: Moving to center of operating table to meet left grasper | O
RG5 | Right carry ring: Hovering with ring between jaws for left grasper to pick | O
RG6 | Ring transfer: Holding ring together with left grasper | O
RG7 | Right pick ring: Opening jaws to let go of ring | O
RG8 | Moving aside | O/C
LG0 | Idle state (or hovering) | C
LG1 | Left grasper: Moving to center of operating table to meet right grasper | O/C
LG2 | Left pick ring: Positioning ring between the jaws | O
LG3 | Left pick ring: Clasping ring | O
LG4 | Left carry ring: Moving horizontally (straight or diagonally) towards a peg on left side of operating table | O

Gesture Index

(Right) and

(L: Left)

Objects Movement

Jaws (Open

or Closed)

LG5 | Left carry ring: Positioning ring over peg | O
LG6 | Ring on peg: Opening jaws and dropping ring through peg | O/C
LG7 | Ring on peg: Moving aside after transferring all three rings | O/C

### 6.2.1.2. Deep Learning: Single Shot Detection (SSD)

After setting up a comprehensive gesture model, our next task is implementing gesture

detection using deep learning, primarily via Single Shot Detection (SSD). A single-shot detector

is a one-phase detector that predicts multiple classes. In other words, a real-time gesture detection

framework that merges the tasks of object localization and type into a single unified architecture

[27]. This section will discuss the training process as shown in Figure 18, including data

preparation, annotation, and fine-tuning hyperparameters to optimize the model's performance for

our specific use matter. Challenges encountered, methods used to overcome them, and the initial

results will also be presented, delivering a clear view of the progress made and the steps forward.

### 6.2.1.2.1. Dataset Collection and Preparation

For this task, we have created a dataset from laparoscopic training videos, each ranging

from 75 seconds to 2 minutes. This dataset includes frames extracted from these videos, carefully

annotated to function as a training foundation for our SSD model. The annotation process was

facilitated using LabelImg, an open-source image annotation tool [28], which enabled the labelling

process and resulted in each image having an associated .xml file. These .xml files were

transformed into .csv files for an overview and. tfrecord files for use in the training pipeline. Upon

completing the annotation process, we classified the images and their corresponding .xml, .csv,

and. tfrecord files into separate datasets for training, testing, and evaluation, following an 80:20 split. This split is created to deliver a complete training experience while ensuring a thorough

validation of the model's effectiveness.

### 6.2.1.2.2. Label Map

A required component of the dataset preparation was preparing a label map. This map is a

directory for the training and detection algorithms, linking each gesture class to a specific integer

value. For the dataset, we formulated a label map with 15 unique labels; each label corresponds to

a particular laparoscopic peg transfer gesture, such as 'RG1' for the first gesture involving the right

grasper, 'LG1' for the left grasper, and so forth, as shown in Figure 19 These labels are instrumental

for the SSD model to recognize and categorize the precise gestures performed during the

laparoscopic procedures. Then, the label map is saved in a. pbtxt file format and is required to train

the SSD model to accurately identify and classify the different instruments observed during

detection. Figure 19 illustrates an example of our label map configuration.

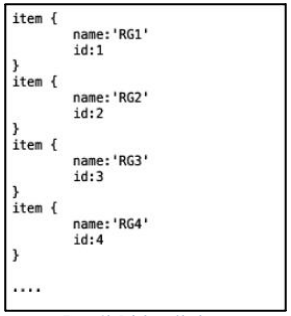
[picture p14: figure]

Figure 19: Label map file classes.

### 6.2.1.2.3. Data Augmentation

In the data augmentation phase of our project, we used the TensorFlow Object Detection

API Image Preprocessor tool to introduce variations to our dataset [30]. This step was necessary and reassuring, as it improved the model's ability to perform under various states without

compromising the integrity of the original data. Our augmentation techniques, including random

horizontal flips and adjustments to brightness and contrast, are instrumental in training the model

to accurately identify and classify gestures under various lighting conditions and orientations,

thereby showcasing its robustness.

Including data augmentation options in our pipeline configuration emphasizes robust

training. For instance, the `random_horizontal_flip` and `random_crop_image` options within our

pipeline config file's `train_config` section introduce randomness and variability into the training

process. This helps create a more adaptable dataset and significantly improves the model's

generalization ability, making it more adept at recognizing gestures in previously unseen images.

[29].

### 6.2.1.2.4. Model Architecture

For our model's foundation, we selected the SSD MobileNet v2 320x320, pre-trained on

the COCO 2017 dataset, from the TensorFlow 2 Detection Model Zoo [29]. This model is a useful

starting point for training on our dataset, effectively good speed, and precision for real-time

recognition tasks. The architecture, shown in Figure 20], includes a feature pyramid network

(FPN), improving the model's ability to accurately detect objects across different scales.

The SSD MobileNet V2 architecture uses depthwise separable convolutions—a

computationally efficient option to standard convolutions—allowing for faster processing without

a substantial loss in accuracy. This feature is important for real-time applications, as our project

required immediate surgical gesture detection. As the model processes input frames, such as the

'Input for RG1' displayed, it generates bounding boxes at multiple scales, pinpointing the location

of surgical gestures within the frame.

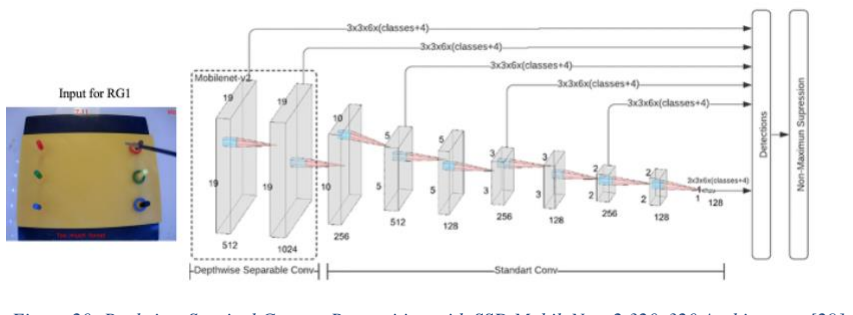
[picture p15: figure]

Figure 20: Real-time Surgical Gesture Recognition with SSD MobileNet v2 320x320 Architecture [29].

Our pipeline configuration refines our pre-trained model to classify 19 classes. To improve

the model's efficiency and effectiveness in extracting features, we use the RELU activation

function within the convolutional layers. Additionally, we have specified important

hyperparameters such as the depth multiplier, minimum depth, and L2 regularization to ensure that

the model performs optimally.

Our training process adopts a batch size of 4 and includes data augmentation techniques

such as random horizontal flips and random cropping. These techniques help improve the model's

generalization ability based on the training data. The process is also supported by a momentum

optimizer with a cosine decay learning rate set to 11k steps, ensuring a robust learning curve. Our

model's efficiency is an important aspect of its success. One feature is the weight-shared

convolutional box predictor in the `box_predictor` settings. This feature reduces the computational

burden by sharing weights across various feature maps, eventually optimizing the model's

performance. Further, the model is equipped with a detailed anchor generator and post-processing

configurations, which, coupled with the weight-sharing feature, allow it to reach high precision

when detecting surgical gestures.

Overall, this setup, from the architectural choices to the training regimen, positions our

model as a competent tool for detecting surgical gestures in real time and lays a solid foundation

for advancing surgical training simulations.

### 6.2.1.3. Evaluation

We developed a system capable of identifying and categorizing various gestures in images.

We then assessed it using several metrics, including precision and recall. Precision scores indicate

whether the system makes accurate judgments, while recall allows us to determine whether it

misses critical information. By analyzing these metrics, we evaluated the system's accuracy and

completeness.

We tested our system to evaluate its ability to recognize and categorize differently. The

results of this test are shown in Figure 21. Figure A shows the system's real-time output,

demonstrating the detected gestures. At the same time, Figure B is a reference for the system's

expected performance, showing the manually labelled gestures. We found that the system

identified certain gestures with confidence, such as 'RG0' for the right grasper in idle position and

'LG5' for the left grasper positioning the ring over the peg, as depicted in the annotated test images

in Figure 23. Initially, the system's detection of these gestures is quite good, with 'RG0' identified

with a 52% confidence level and 'LG5' at 68%. These percentages reflect the precision of our

system, which is its ability to label gestures it sees in the training videos correctly.

Figure 21: Comparative Analysis of Automated Accurate Gesture Detection: SSD MobileNet v2 320x320 vs. Manual Labeling. Figure (A) on the right and Figure (B) on the left.

During a recent test, the system demonstrated a successful detection, with the model

identifying the correct gestures shown in Image C Figure 22. However, the system encountered

some limitations in its performance. For example, as shown in Figure 22, Image D, the system incorrectly identified a gesture as 'RG8' with a 42% confidence score instead of recognizing it as

the correct 'left gesture. This highlights the need for further system accuracy enhancements,

especially in critical applications like surgical training, where precision is paramount.

To improve the system's performance, we need to expand the training set and fine-tune the

model parameters. This will help us achieve a better balance between precision and recall, which

is crucial for developing a robust design that can reliably support the complex requirements of

gesture recognition in various environments.

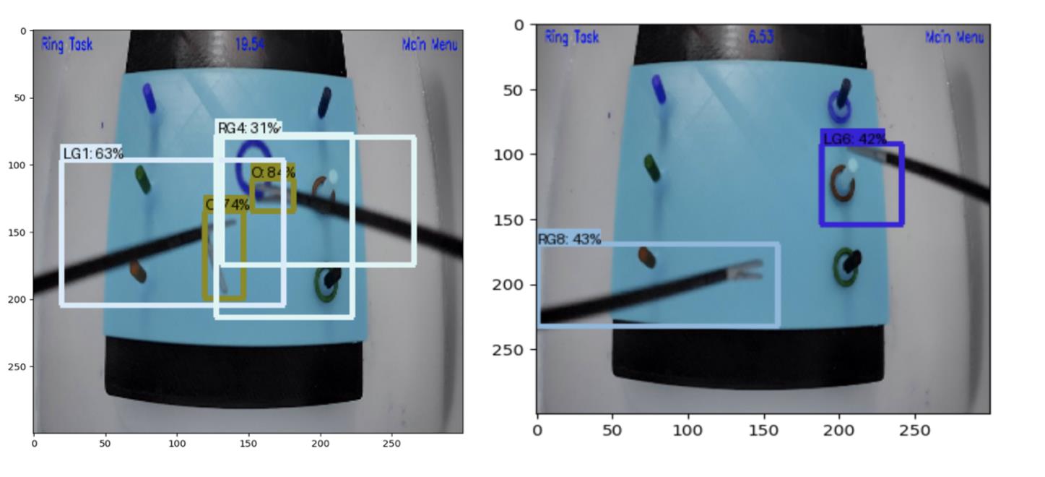
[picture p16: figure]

Figure 22: Comparative of Automated Accurate Gesture Detection on the right (Image C) and inaccurate on the left Image(D).

### 6.2.1.4. Results

During the testing stage, we developed a detailed script to automate the detection and

labelling of surgical gestures from video data. The script loaded the pre-trained model, processed

each video frame, and applied the detection function to identify gestures within the footage.

Whenever a gesture was detected with adequate confidence, the script recorded the event in a CSV

file and its timestamp, creating an organized log for performance analysis as shown in Table 4.

Table 4: The automated output logging Gesture.

Time Start | Time Stop | Right Gesture | Left Gesture
| 0.06666666666666670 | RG0 | LG0
0.06666666666666670 | 0.13333333333333300 | RG0 | LG6
0.13333333333333300 | 0.26666666666666700 | RG0 | LG0
0.26666666666666700 | 0.3333333333333330 | RG0 | LG6
0.3333333333333330 | 0.4 | RG0 | LG0
0.4 | 0.6666666666666670 | RG0 | LG6

### 6.2.2. Model Improvement

Timely and accurate feedback is crucial for improving the efficacy of surgical training.

However, the traditional approach, which relies on manual evaluation for feedback, can be

subjective, inconsistent, and resource intensive. Additionally, manually labelling surgical gestures

in training videos for feedback purposes is time-consuming and prone to human error. This

limitation restricts delivering immediate, objective, and detailed performance analysis. The

reliance on manual approaches to evaluate surgical training activities poses a substantial barrier to

reaching the highest standards of surgical proficiency. This approach must be adjusted to maintain

training efficiency and feedback quality. There is a clear need for a technology-driven solution

that enhances the accuracy and reliability of performance assessments in surgical training by

streamlining the feedback mechanism.

### 6.2.2.1. Integrating Spatiotemporal Dynamics with Self-Supervised Learning in Video

Analysis

The previous method of analyzing surgical training videos focused on spatial features. This

model involved examining each frame separately to detect gestures and movements, like reviewing

a series of snapshots independently to deduce what is happening. This technique can be effective for recognizing certain gestures based on visual cues within a single frame but lacks the contextual

understanding of movement over time. Understanding complex surgical gestures that unfold across

several frames is important. Hence, a more comprehensive approach is needed to provide a better

understanding of the movement of surgical instruments over time. Such an approach would require

analyzing the gestures and movements in the context of the entire surgical procedure rather than

examining each frame independently. The proposed system's architecture captures the intricate

movement patterns of surgical procedures by breaking down the video clip into smaller clips. This

results in a detailed timeline of movement. Figure 23 shows that the process starts by pre-

processing peg transfer task videos, which are then sub-sampled and resized to ensure

compatibility with the model's input requirements. These videos' extracted clips and volumes serve

as the foundation for analyzing the short-term (ST) and long-term (LT).

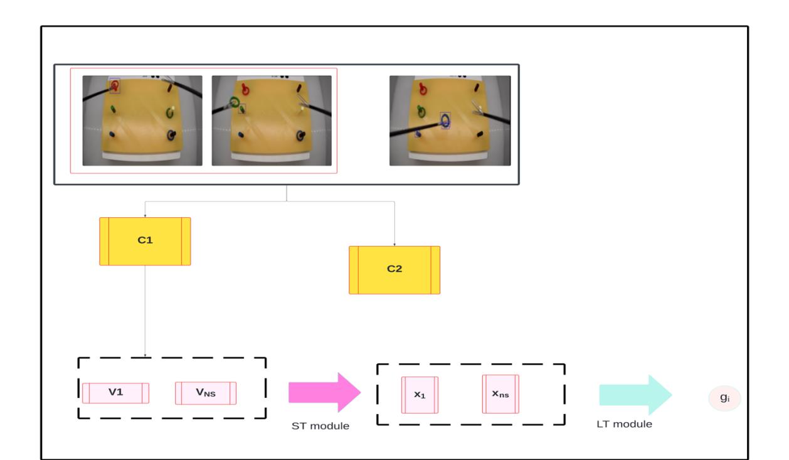
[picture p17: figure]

Figure 23: Workflow of Gesture Recognition Architecture.

Our primary objectives as mentioned in the task description section remain the same:

- Tailored Gesture Modelling for Training.

Our first objective was to develop a gesture modelling system tailored to the peg transfer

training task. However, we have reduced the number of gesture indexes to improve the model.

This refinement is reflected in the updated gesture classifications, as shown in Table [2], resulting

in a more precise and defined set of classes. We simplified the model without compromising its

complexity, enhancing its clarity. One of the main challenges in gesture recognition in this context

is the repetitive nature of certain movements, making it difficult for the model to distinguish

between different gestures accurately. However, our focused approach ensures that the model

remains proficient and nuanced in its operational output. The updated gesture model is now more

user-friendly and manageable, making it an effective training tool. Based on the description of the

peg transfer task, an updated performance required the following sequence of gestures:

PT: RG0→ RG1 → RG2 → LG1 → RG3 → LG2→ RG0 → LG3 → LG4

Table 5: The Modified Gestures Classification by Movement and Location.

Gesture Index | Gesture Description | Jaws (Open or Closed)?
RG0 | Idle state (or hovering) or moving aside | C
RG1 | Moving vertically downwards towards peg on right side of operating table and Positioning ring between the jaws and clasping it | O/C
RG2 | Moving to meet left grasper | O
RG3 | Handing ring to left grasper to pick | O
LG0 | Idle state (or hovering) or moving aside | C
LG1 | Moving to center of operating table to meet right grasper. | O
LG2 | Positioning ring between the jaws and clasping it and moving horizontally (straight or diagonally) towards a peg on left side of operating table | O
LG3 | Positioning ring over peg and dropping ring through peg | O
LG4 | Moving aside after transferring all three rings | O

### 6.2.2.2. Labelled Data

We selected a single video to create a labelled dataset, focusing on the gestures necessary

for the peg transfer task. We used the Computer Vision Annotation Tool (CVAT) to label each

gesture in the video precisely. We classified these gestures into 12 different categories, such as

RG1 to RG3 for actions performed with the right grasper, LG1 to LG4 for movements with the

left grasper, 'O' and 'C' for the open and close states of the tool jaws, and 'unknown' for any gestures

that did not fit the predefined classes. Through annotation, we ensured high-quality, accurately

labelled data for a robust learning foundation.

### 6.2.2.3. Unlabelled Data

We used an unlabeled video in combination with our labelled dataset to improve the

performance of our model using a semi-self-supervised approach. The unlabeled video

experienced the same preprocessing steps as the labelled one without detailed gesture annotations.

Our decision to include the unlabeled data was a strategic move to enhance the model's ability to

learn from unannotated segments due to the low amount of labelled data. This approach can reveal

patterns and features not explicitly marked in the labelled dataset.

### 6.2.2.4. Video Dataset Processing

We needed to process these videos to ensure they were compatible with our model's

requirements. The videos were recorded at 15 frames per second (fps), but we subsampled them

to 25 fps and resized them to 224 × 224 pixels to fit the pretrained model. This resizing made the

videos appropriate for the model's input shape and improved the training process's computational

efficiency.

After the initial preprocessing, the videos were divided into smaller clips and volumes for

a more detailed analysis. The clips were extracted with a step size of 3 frames, each lasting 15.

The volumes were further decomposed with a step size of 1 frame, resulting in 8 frames per

volume. This split allowed the model to examine the surgical tasks at different detail levels, from

comprehensive clip-based movements to better volume-based gestures [31].

These clips and volumes were obtained from labelled and unlabeled datasets and fed into

different CNN architecture modules. As shown in Figure 23, they performed as the foundational

data for training our model's short-term (ST) and long-term (LT) components. This data

annotation, labelling, and preprocessing approach ensured a comprehensive and nuanced dataset

for training an advanced gesture recognition model for our training simulations.

### 6.2.2.5. Short Model: Semi Self-Supervised Learning with ST Model

The ST module uses a self-supervised learning strategy and an encoder-decoder

mechanism to extract spatiotemporal features. This approach is designed to reduce the reliance on

much-annotated datasets. Hence, the model training process is streamlined, especially for complex

tasks such as surgical gesture recognition. As shown in Figure 24, in the Short-Term (ST) module

of the model, the process starts with the input video volume (V). This volume transforms the

Inception3D (I3D) network, operating as an encoder. The I3D network compresses (Vi) into a

deep feature vector (Xi), capturing the spatial features and the initial temporal details within the

sequence.

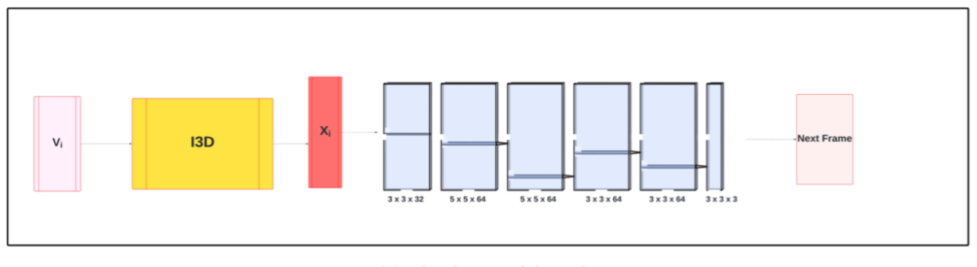
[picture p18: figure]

Figure 24: The Short Module Architecture.

### 6.2.2.5.1. Encoder: Inception3D (I3D) Network

Our encoder is the Inception3D (I3D) architecture. We selected this architecture for its

ability to understand spatial features within a temporal frame. The I3D encoder is pre-trained on

the Kinetics-400 dataset and is trained in processing RGB inputs, providing a reliable foundation for our model to build upon. This encoder compresses a video volume into a compact feature

vector, encapsulating the spatiotemporal features needed for the next decoding phase [32].

### 6.2.2.5.2. Decoder: TransConv2D Architecture

As shown in Figure 24, In our model, the decoder is responsible for reconstructing

subsequent video frames from the compact feature vectors encoded by the I3D network. This is

achieved through a sequence of TransConv2D layers that allow the model to learn the complexities

of surgical gesture dynamics over time. The deep features (Xi) progress through the TransConv2D

layers, with each layer using ReLU activation and batch normalization to improve refinement.

Dropout layers are also included to prevent overfitting, ensuring the model generalizes well to

new, unseen data. The model restores the spatial details condensed during the I3D encoding phase

by upscaling the feature maps through the decoder. This ensures the model comprehends the spatial

and temporal nuances of the surgical gestures. The final step, the final layer, a Sigmoid activation

function is used to output the reconstructed frame, normalized between 0 and 1. This output mimics

the next frame in the sequence, which teaches the model to learn the flow of movement in surgical

tasks. [31]

### 6.2.2.5.3. Semi Self-Supervised Training Approach

We aim to reduce the need for manual annotation efforts, and we achieve this with the ST

Model by using a semi-self-supervised training methodology. The model uses a significant portion

of unlabeled data for training and learns to predict the next frames, therefore understanding gesture

dynamics autonomously. Additionally, we use a smaller subset of labelled data, annotated with

tools like CVAT, to fine-tune the model and ensure accurate gesture recognition.

During the model training, a strategic approach called pseudo-labelling is applied. This

technique involves the model assigning predicted labels to unlabelled data using the knowledge it acquired through training. A "BalancedBatchSampler" creates training batches, ensuring a

balanced mix of labelled and pseudo-labelled data. The model is evaluated multiple times to

optimize its accuracy and prevent overfitting. This evaluation process involves implementing an

early stopping protocol and using checkpoints to capture and retain the model's most effective

states.

### 6.2.2.6. Integration with LT Module

Due to time constraints, the Long-Term (LT) module has not been fully implemented.

However, its implementation is planned for future improvements to enhance the model's ability to

capture long-term dependencies in surgical gestures. The LT module will use a transformer

architecture and feature vectors generated by the ST model to analyze sequences of gestures over

extended periods, providing a comprehensive analysis of surgical tasks. The ST Model is an

improvement for our gesture recognition technique. It uses a semi- self-supervised training

approach, which reduces reliance on comprehensive annotations while improving the model's

ability to learn complicated spatiotemporal patterns in peg transfer procedures. This method

improves the model's performance and makes adapting to new tasks and datasets easier.

### 6.2.2.7. Evaluation and Analysis of ST Model

Evaluation and Analysis of ST Model The confusion matrix in Figure 25 is an evaluation

tool for our ST Model. It quantifies the model's predictions, with the rows representing the actual

classes and the columns depicting the predicted classes. Diagonal elements denote accurate

predictions, whereas off-diagonal elements indicate misclassifications. For example, class 'RG0'

(index 0) and class 'RG1' (index 1) correctly show most of their predictions on the diagonal,

indicating high accuracy for these gestures. Conversely, overlaps in predictions between 'LG2'

(index 6) and 'LG4' (index 8), or between 'LG3' (index 7) and 'O' (index 9), indicate challenges the model faces in distinguishing these gestures due to their feature similarity. Also, this matrix shows

that while the model can correctly predict the 'C' gesture for closing jaws (index 10) with high

precision, it also frequently confuses the 'unknown' class (index 11) with 'LG4' (index 8), which

could indicate a fault in the representation of the unknown class within the training data.

After analyzing the confusion matrix, we can identify the categories where the model

performs well and those where it struggles. We can expand the dataset by adding more diverse

samples of the 'unknown' gesture to improve the model. This will expose the model to a wider

range of gestures not included in the predefined categories, resulting in more accurate

classification. Also, we can review and refine the feature extraction process to better distinguish

between similar classes. These measures aim to improve the model's generalization ability and

increase the accuracy beyond 60%.

Figure 25: Matrix of ST Model.

### 6.3. Data Processing Pipeline

### 6.3.1. Initial Processing

In the latest development of our laparoscopic surgery simulator, the processing of real-time

data during simulations is efficiently managed by an Arduino microcontroller. This setup is ideal

for seamless data acquisition from each sensor through a signal controller. The system captures a

comprehensive dataset, including rotation, position, speed, acceleration, and force parameters. A

significant step in this phase is differentiating between each metric’s various measures. Text files

are used to store the raw data collected from the sensors. Therefore, a Python script was developed

to facilitate the rapid processing of this data. This script includes a dialogue window using the

‘tkinter’ library that allows users to select the appropriate text file containing sensor data for

cleaning. Following the selection, the data is cleaned, organized into a DataFrame, and saved as a

CSV file using the ‘pandas’ library, enhancing the efficiency of data visualization and preparation

for subsequent algorithms and processes.

### 6.3.2. Data Segmentation

The subsequent phase in our data processing and preparation pipeline involves a critical

step: segmentation. This process entails dividing the entire procedure into three distinct subtasks.

Each ring is a subtask with a total of 3 rings. Such segmentation proves immensely beneficial for

multiple aspects of our system:

A. Enhanced Algorithm Feeding: By breaking down the procedure into smaller,

manageable subtasks, we can feed data into our algorithms in a more structured and effective

manner. This segmentation allows the algorithms to process data in chunks that are more

representative of specific aspects of the procedure, leading to more accurate and relevant

outcomes.

B. Refined User Performance Evaluation: Segmenting the procedure enables a more

granular evaluation of the user’s performance. By analyzing each subtask independently, we better

understand the user’s strengths and areas needing improvement. This detailed approach ensures

that performance assessments are holistic and nuanced, capturing the complexities of the user’s

interactions with the simulator.

C. Targeted Feedback for Improvement: One of the primary objectives of our simulator

is to provide constructive feedback to users. The feedback can be specifically tailored to each

segment by dissecting the procedure into subtasks. This targeted feedback is instrumental in

guiding users on improving their performance in each specific area of the procedure, ultimately

enhancing their overall skill set.

Segmenting the data into these subtasks was executed using Python. Here is an overview

of how this was achieved:

### 1. Class Initialization - ‘DataSegmentation’: This class forms the foundation for

segmenting the data. It initializes with three critical file paths: ‘CleanedSensorData_Ref.csv’ for

the expert’s cleaned sensor data, ‘user_file_path’ for the user to select their procedure data through

a file dialogue interface, and ‘Labelled Videos.xlsx’ for essential labelled information used in

segmenting with deep learning methods used in section 6.2.

### 2. Loading Data - ‘load_data’ Method: This method is vital for importing necessary

datasets into the Python environment for processing. It uses ‘pandas,’ a powerful data analysis

library, to read cleaned reference and user data from CSV files and the labelled information from

Excel sheets. The data from two procedure videos, one for an expert and one for the user, are

loaded separately with their respective labels, which is critical for comparative performance

analysis.

### 3. Processing Segments - ‘process_segments’ Method: This method takes the loaded data

and labels as inputs, creating data segments based on specified timestamps in the labels. It iterates

through each row in the labels DataFrame, filtering corresponding rows. This step is crucial for

isolating specific portions of the time series data for focused analysis on defined intervals of each

subtask.

### 4. Combining and Saving Segments - ‘combine_and_save_segments’ Method: This

method consolidates individual segments into more significant task-specific segments. Segments

are grouped using predefined ranges based on the labels Excel sheet, forming a comprehensive

dataset for each subtask. These concatenated segments are then saved as new CSV files, named to

indicate the source video and the specific subtask segment. This organization of data is vital for

subsequent independent analysis of each subtask.

### 5. Execution - ‘run’ Method: This method orchestrates the entire segmentation process. It

calls the load_data method to import datasets, process_segments to create individual time-based

segments and then combine_and_save_segments to compile these into subtask-based datasets.

This method processes reference and user data, setting the stage for comparative analysis using the

Dynamic Time Warping (DTW) algorithm in later stages.

6. Overall Significance: The segmentation phase is integral to the project as it structures

the data into meaningful and analyzable parts. Breaking down the data into specific segments based

on labelled time intervals allows for more precise and focused analysis for each subtask. This

structured format is essential for the upcoming steps, where the DTW algorithm will be applied to

each segment for detailed time series analysis and comparison.

In summary, the data segmentation process is a systematic and crucial step. It transforms

the cleaned data into well-defined segments, preparing it for the following intricate analysis,

including the application of the DTW algorithm and the subsequent evaluation of user performance

against the reference data, as well as for better visualization.

### 6.4. Performance Evaluation

### 6.4.1. Time Series Alignment and Performance Comparison in DTW

Data mining involves sifting through raw data to uncover underlying patterns and extract

valuable insights [33]. This process can vary significantly among individuals, leading to notable

differences in the duration and pacing of data analysis between users and experts in a laparoscopy

surgery setting. Dynamic Time Warping, or DTW, would come into play in this regard. DTW is a

method used to calculate the optimal matching between two sequences that may not be perfectly

synchronized, often temporal in nature [34]. This technique is prevalent in various fields, including

data mining, speech recognition, and financial markets.

DTW leverages dynamic programming to find the best temporal match between elements

of a two-time series. An advanced form of DTW, online and dynamic time warping, has been

proposed to enhance time series data mining efficiency. This approach involves segmenting a long

time series into shorter subsequences and then applying DTW to measure the similarity of each

pair of subsequences [35]. To effectively compare a user's performance with an expert, it is

essential to align the user's time series signals with the reference ones, simulating concurrent

completion of the procedure. The alignment process is structured as follows [36]:

A. Each index in the first sequence must correspond to one or more indices in the second

sequence, and the reverse must also hold true.

B. The initial index of the first sequence should align with the first index of the second

sequence. However, this need not be its exclusive match.

C. Similarly, the final index of the first sequence should align with the last index of the

second sequence without being restricted to a singular match.

D. The mapping from indices of the first sequence to those of the second must show a

monotonically increasing relationship, and the same applies in reverse. This means if ‘j > i’ are

indices from the first sequence, there must not exist two indices ‘l > k’ in the second sequence

such that index ‘i’ aligns with ‘l’ and ‘j’ aligns with ‘k,’ and vice versa.

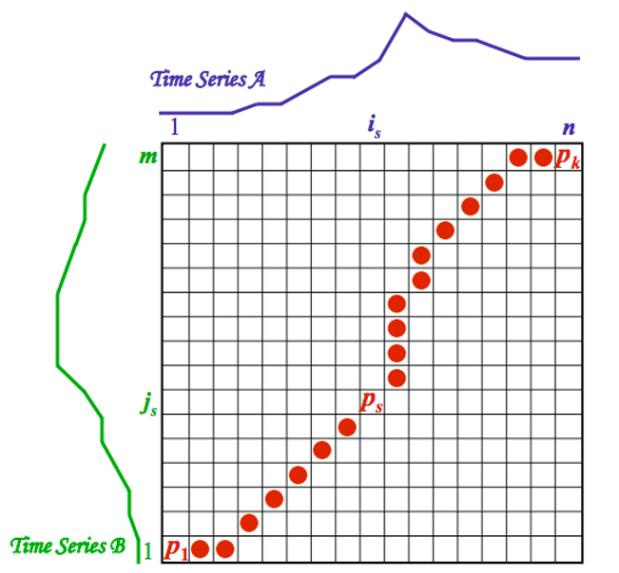
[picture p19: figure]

Figure 26: Series A and B distance normalized over time [36].

Mathematically, DTW arranges two sequences, X and Y, into an n-by-m grid. Each point

in this grid represents the alignment between elements of X and Y [36]. The warping path W is

then computed to map the elements of X and Y to minimize the distance between them. This path

is essentially a sequence of grid points.

Dmin(ik,jk

) = min
ik−1,jk−1

Dmin(ik−1
,jk−1

) + d(ik,jk

|ik−1
,jk−1

) (3)[36]

Calculating the optimal path to a specific point (ik, jk) involves using Euclidean distance.

Subsequently, the overall path cost is calculated, representing the cumulative distance over the

warping path. Here is an actual example of how it works:

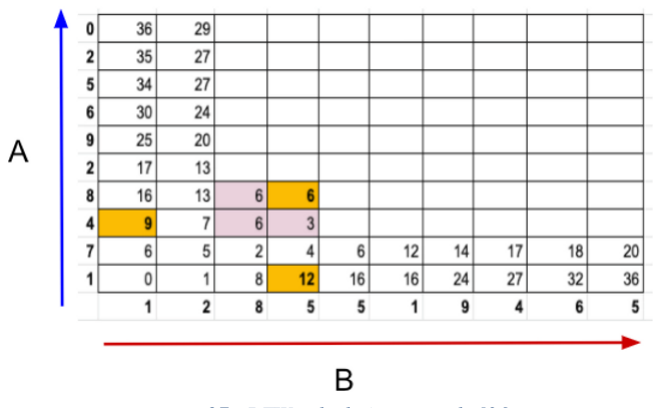
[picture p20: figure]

Figure 27.: DTW calculation example [36]

Consider two-time series, A and B, represented on the A and B axes. To calculate the value in the

yellow highlighted block (6), we use the following equation:

M(i,j ) = |A(i) − B(j)| + min(M(i − 1,j − 1), M(i,j − 1), M(i − 1,j)) (4)[36]

For example, |8 –5| + min(6, 6, 3 ) = 6. Once the calculation for the entire matrix is completed, we

compute the warping path to obtain the DTW distance, as illustrated in the following figure:

Figure 28: Cost matrix with its final path [36].

The paths are chosen based on the minimum value criterion: The DTW distance, D, is calculated

as the average of the computed values over the total number of chosen paths:

D =

17 + 12 + 9 + 9 + 9 + 7 + 7 + 6 + 3 + 2 + 1 + 0
12 | = 6.83

Moreover, DTW implementation requires consideration of certain constraints to ensure

efficiency and accuracy. These include the boundary condition, which ensures the warping path

starts and ends with both signals' start and end points, which is shown in the aligned signal in

Figure 30; the monotonicity condition, preserving the time order of points; and the continuity

condition, which limits the path transitions to adjacent points in time. The warping window

condition can also restrict allowable points within a specific width.

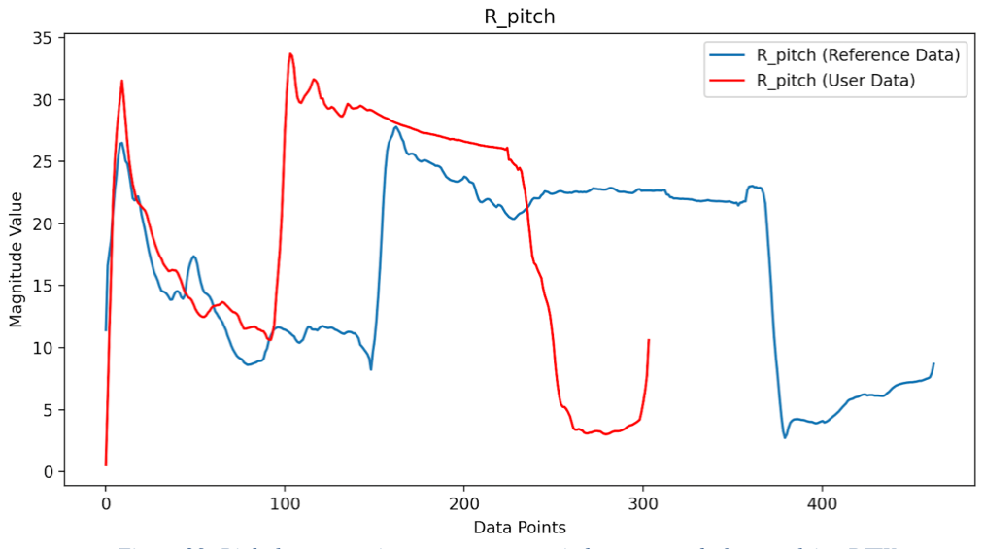
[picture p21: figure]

Figure 29: Right laparoscopic surgery grasper pitch movement before applying DTW.

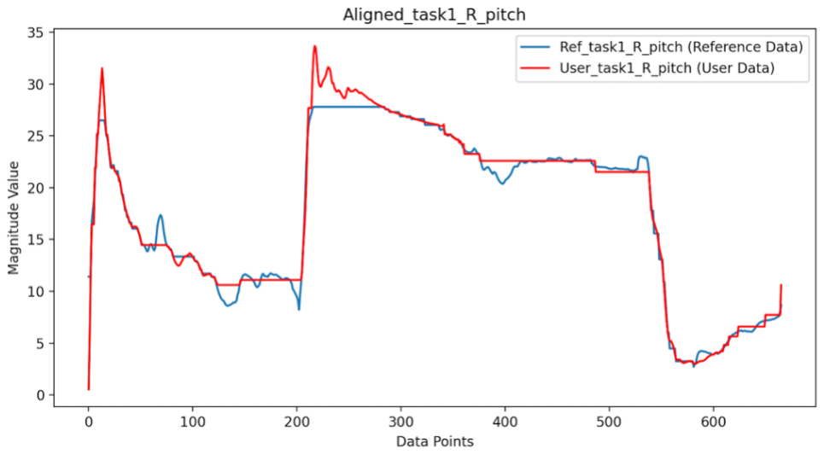
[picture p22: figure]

Figure 30: Right laparoscopic surgery grasper pitch movement after alignment using DTW.

In summary, DTW is a powerful technique in data mining for aligning and comparing time

series data, especially when there are variations in timing or speed between sequences. Its

mathematical foundation and constraints make it a robust and efficient method for analyzing

temporal data from the laparoscopy surgery simulator sensors.

### 6.4.2. TaskPerformanceAnalyzer: Python Class for Time Series Analysis

A Python Class for Time Series Analysis, the TaskPerformanceAnalyzer class is designed

to analyze and compare performance in tasks involving video data and associated time series

signals. Upon initialization, the class takes paths to the segmented reference and user data in CSV

and video formats that were done in section 6.3. It uses the ‘pandas’ library to load and process

the CSV data, dropping unneeded columns and recording signal column names. The class features

a custom method, dtw_distance, to compute the Dynamic Time Warping (DTW) distance between

two-time series, as explained earlier. This function establishes a matrix and iteratively calculates

the minimum distance, reflecting the series's similarity despite potential timing or speed variances.

The align_data method employs the ‘fastdtw’ function, an efficient DTW implementation for data

alignment. This method aligns the reference and user data based on DTW distances and saves the

aligned data into a new CSV file.

The class also includes a step for normalizing to keep the data well-behaved and processing

data in fixed size moving windows, typically set to 10 seconds for better analysis. It calculates the

DTW distance for each window, categorizing performance and saving results, including statistics

like mean, maximum, minimum, and standard deviation of DTW distances, for further analysis. In

the video processing stage, the class uses the DTW distance analysis to pinpoint segments in the

reference and user videos where the user’s performance significantly diverges. This step is done

by setting a threshold of the mean DTW distances in all moving windows added to one standard deviation so that any distance that exceeds this threshold will be detected and presented to the user

in the upcoming stages. Then, these segments are extracted using the ffmpeg_extract_subclip

function from the ‘moviepy’ library. The extracted clips, highlighting weak performance areas

compared to the expert data, are then combined, and annotated with text labels for clarity, as shown

in Figure 31 (Youssef is the user, and Atallah is the expert in this case)

Figure 31: Video tool showing areas for improvement in Youssef's performance (the user).

In the illustrative Figure above of the tool's interface, we observe a split-screen comparison

that plays a crucial role in the analysis and enhancement of surgical skills. On the left panel labelled

‘User (You)’ (Youssef in this case as mentioned), we see a segment of a trainee's performance,

whereas the right panel, marked 'Expert' (Atallah), displays the corresponding segment from an

expert surgeon's procedure supposedly. These are specific moments where the tool has identified

significant deviations in technique or efficiency between the user and the expert. Timing metrics

are visible at the top of each panel, allowing for precise comparisons down to the second. Below the video playback, the interface provides controls and a progress indicator, 'Number of Clips to

Watch, as shown in Figure 31, which assists in navigating through the segmented procedural tasks.

These visual aids are designed to draw the trainee's attention to critical aspects of the procedure,

fostering a direct, comparative learning experience. By focusing on these moments, the simulator

not only aids in recognizing the nuances of skilled performance and provides straightforward,

actionable insights for the trainee's self-improvement. The overall workflow of the class involves

comprehensive analysis through aligning time series data, normalizing and segmenting the data

for detailed examination, and visually comparing video segments where user/trainee performance

differences are most noticeable.

In conclusion, the significance of this section in developing a laparoscopy surgery

simulator cannot be overstated. This innovative tool is pivotal in enhancing surgical training by

offering detailed, informative feedback on trainees' performance. The simulator facilitates targeted

improvement by identifying and displaying clips of areas within each segmented procedural task.

This feature is precious as it allows trainees to refine their skills and address potential weaknesses

independently, without the constant oversight of an expert surgeon. This autonomous learning

approach not only accelerates skill development but also fosters a deeper understanding of surgical

techniques, ultimately contributing to the advancement of laparoscopic surgery education.

### 6.4.3. TaskPerformanceAnalyzer: Python Class for Time Series Analysis

In an effort to enhance the educational experience for trainees in pediatric laparoscopic

surgery, we have developed a cutting-edge chatbot powered by Large Language Models (LLMs),

explicitly utilizing the GPT-3.5 Turbo model through OpenAI’s API. This chatbot is designed to

provide users with a convenient and interactive platform to ask questions and gain insights about various aspects of surgical training. The development of this chatbot was also a part of my

learning journey with LLMs, exploring their potential applications in medical education.

The chatbot is built on a foundation of Python programming and leverages the Streamlit

library to create a user-friendly web interface. Upon initiating the chatbot, users are greeted with

a welcoming message and prompted to ask any questions related to pediatric laparoscopic

surgery as shown in Figure 32.

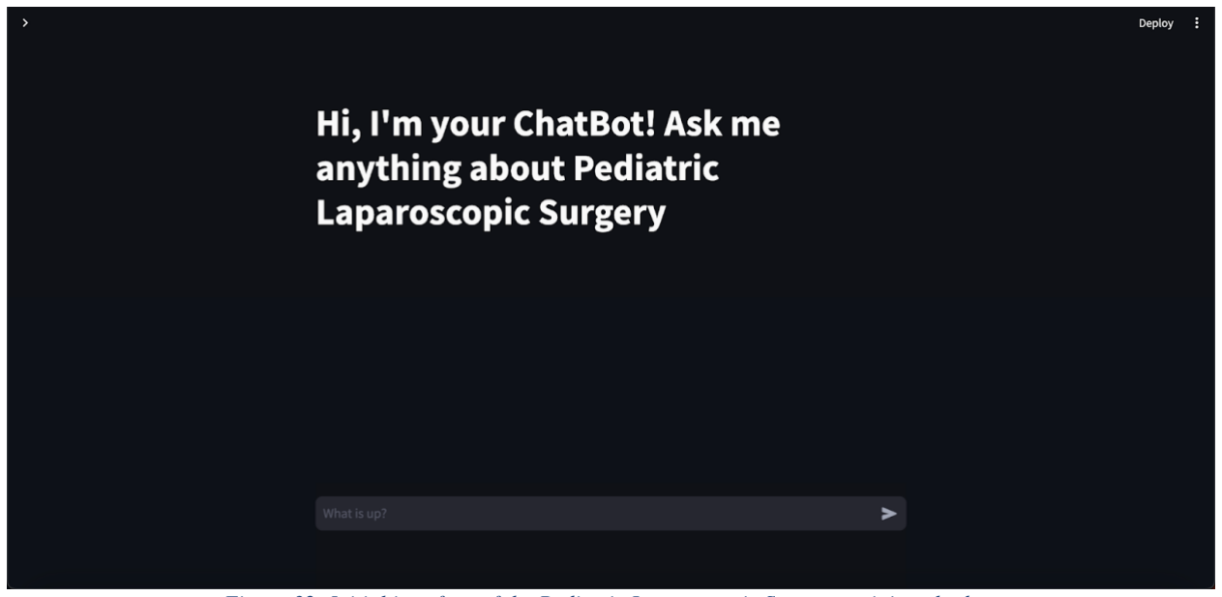
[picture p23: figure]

Figure 32: Initial interface of the Pediatric Laparoscopic Surgery training chatbot.

The chatbot's backend is configured to handle user queries efficiently, processing them

through the GPT-3.5 Turbo model to generate accurate and informative responses. To ensure the

chatbot is equipped with relevant and up-to-date knowledge, we have implemented a system that

allows for the dynamic uploading of textual documents. These documents serve as the knowledge

base for the chatbot, enabling it to provide answers based on the latest research, guidelines, and

best practices in the field of laparoscopic surgery. Users can upload new documents to the

knowledge base, ensuring the chatbot's information remains current and comprehensive. The

chatbot's interface includes a sidebar that allows users to choose between using an existing

knowledge base or uploading new documents as visible in Figure 33.

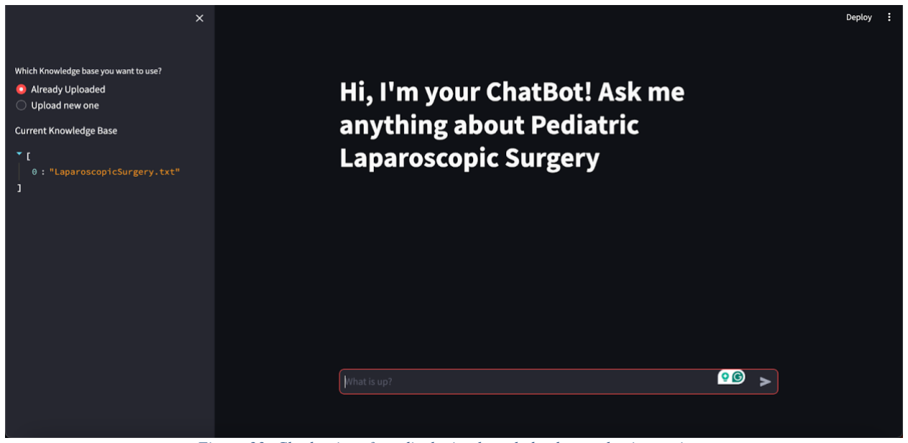
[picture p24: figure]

Figure 33: Chatbot interface displaying knowledge base selection options.

This feature ensures the chatbot can cater to various inquiries, from basic concepts to

advanced surgical techniques. The uploaded documents are processed and stored in a temporary

directory, segmented, and indexed for efficient information retrieval. When a user submits a

question, the chatbot employs a combination of text splitting, embedding, and vector storage

techniques to analyze the query and retrieve relevant information from the knowledge base. The

chatbot utilizes the Chroma vector store and the SentenceTransformerEmbeddings model to

perform similarity searches and identify the most pertinent documents. The matching documents

are then used to generate a comprehensive answer and present it to the user in the chat interface.

The chatbot's implementation includes several features to enhance the user experience,

such as caching to improve response times, dynamic updates to the knowledge base, and the ability

to handle multiple documents. Additionally, the chatbot visually represents the sources used to

construct the answer, offering users transparency and the opportunity to explore the underlying

information in more detail. It is important to note that if a user asks an irrelevant question or one

that is outside the scope of the chatbot's knowledge base, the chatbot is designed not to hallucinate

or provide arbitrary responses. Instead, it will inform the user that the question is irrelevant to the

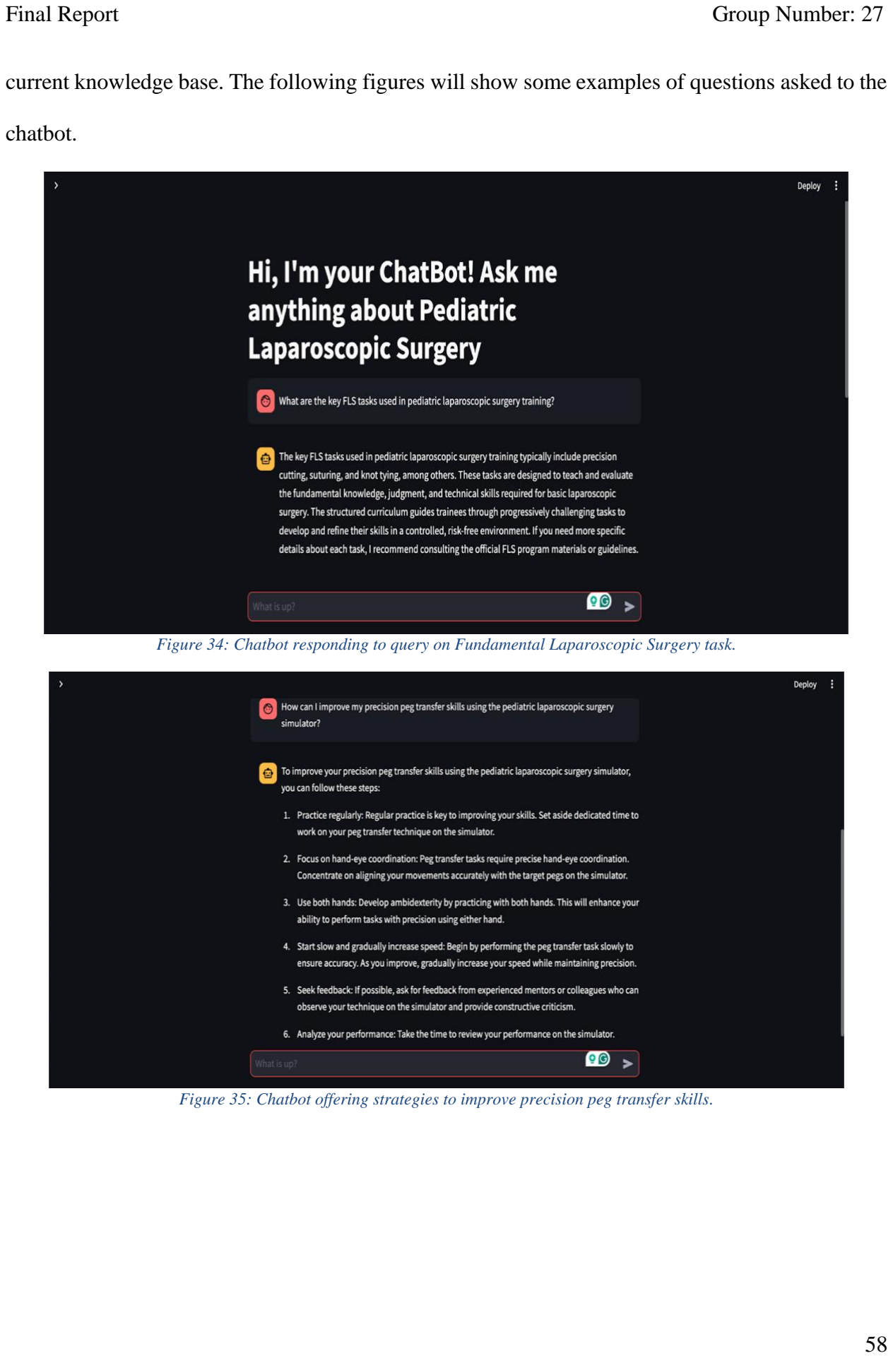
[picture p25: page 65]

current knowledge base. The following figures will show some examples of questions asked to the

chatbot.

Figure 34: Chatbot responding to query on Fundamental Laparoscopic Surgery task.

Figure 35: Chatbot offering strategies to improve precision peg transfer skills.

Figure 36: Chatbot responsiveness to irrelevant and slightly relevant queries.

Figures 34 and 35 show that the chatbot provided informative responses based on the data

uploaded to the database (as shown in Figure 33). However, in Figure 36, when posed with an

irrelevant question, the chatbot gracefully acknowledged its limitations by stating that it didn't

have an answer. Yet, when a slightly relevant question was asked in the second prompt, it offered

a brief response without straying into conjecture and advised seeking guidance from expert

surgeons. Consequently, this chatbot demonstrates its potential as a valuable tool for new trainees

learning on the simulator, provided that the database is populated with the appropriate information.

In summary, the development of this LLM-based chatbot represents a significant

advancement in surgical training. By providing trainees with an interactive and intelligent platform

to ask questions and learn, the chatbot contributes to a deeper understanding of pediatric

laparoscopic surgery. It supports the continuous improvement of surgical skills. While this chatbot

has been a valuable part of my exploration of LLMs, future iterations of the project may decide to

integrate it with the existing user interface or opt not to, depending on its perceived utility and

relevance to the overall training experience.

### 6.5. User Interface Design

In the previous implementation of the pediatric laparoscopic simulator, the user interface

was designed to be a simple application that relied heavily on the precise location of a user’s mouse

movements to progress through the program. In addition, the absence of buttons and relevant

graphics made for a less sophisticated design that would not work with our requirements or our

additions to the data/signal processing element of our program. Thus, this prompted the creation

of a new user interface that would use some functionality of the old program but would be based

on more sophisticated GUI capabilities from Python’s Tkinter library. The subsequent sections

below will present the new and improved user interface, along with the features that were added

to enhance the functionality of the existing program.

For simplicity, and ease of use and integration, Python was chosen as the selected language

to implement the new user interface. Since the old program was built in Python, and the data

processing, signal processing, and machine learning steps are also executed in Python, it was

decided that the language’s tkinter library has extensive GUI capabilities. The object-oriented

programming paradigm will separate large portions of code written using the functional

programming paradigm into distinctly defined classes.

### 6.5.1. The Design Process of the UI

### 6.5.1.1. Developing a prototype

Before initiating the programming process, a prototype for the user interface was developed

to create some sense of organization. However, the actual program looks somewhat different from

what we prototyped, because of multiple modifications and design improvements. Figure 37 shows

some examples from the prototype we developed using Microsoft PowerPoint. This exact moving video background was used in the actual program, however, fonts button sizes, and text

background and layout have changed.

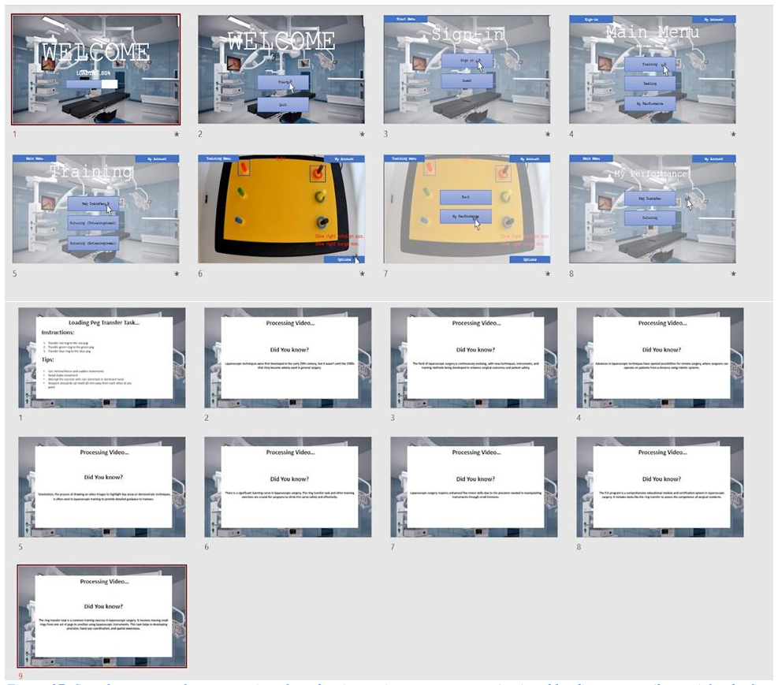
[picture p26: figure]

Figure 37: Sample prototype for our user interface showing various menu screens (top) and loading screens (bottom) for the first iteration of our design.
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

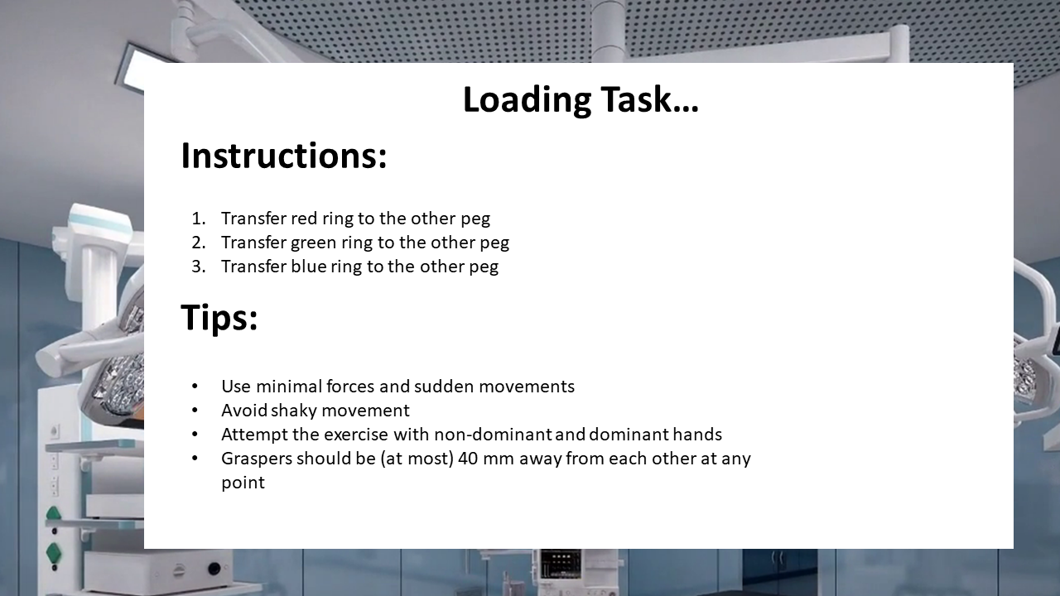
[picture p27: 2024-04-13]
Software/pegtask.png

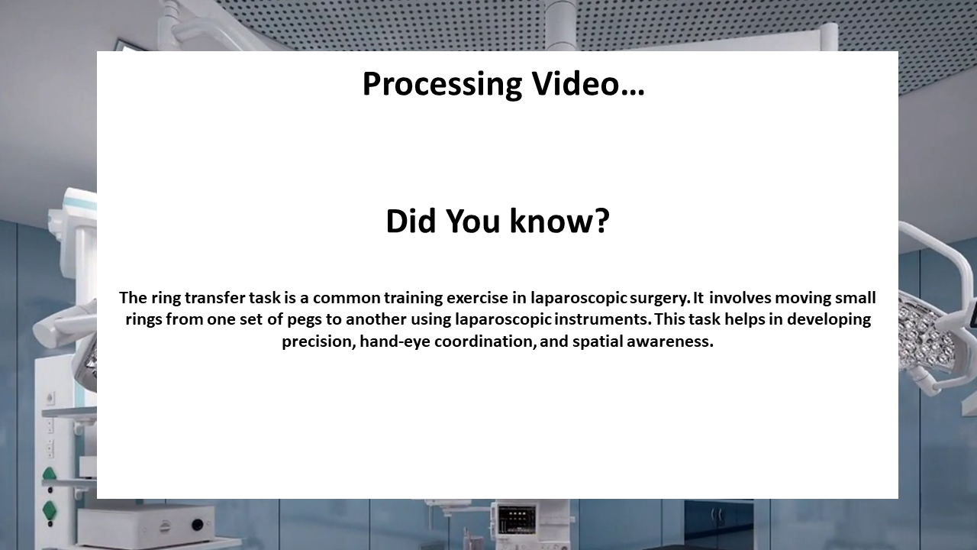
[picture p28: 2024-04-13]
Software/Slide9.PNG

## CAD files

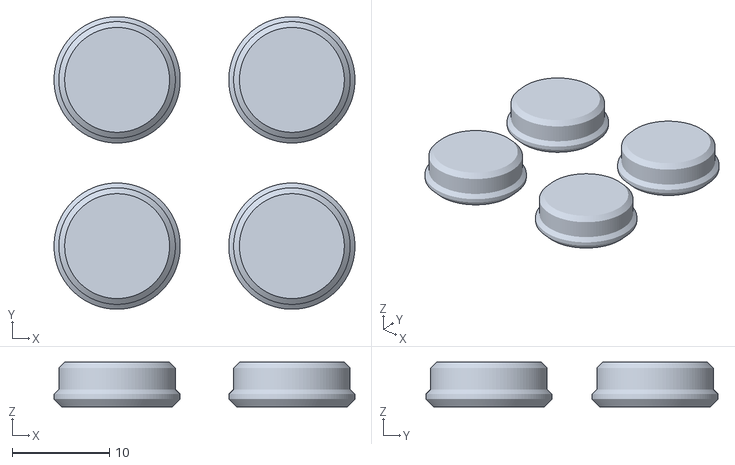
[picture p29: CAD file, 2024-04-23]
Hardware/CAD/screen-setup/Base Feet.stl
31.0 x 30.1 x 4.60

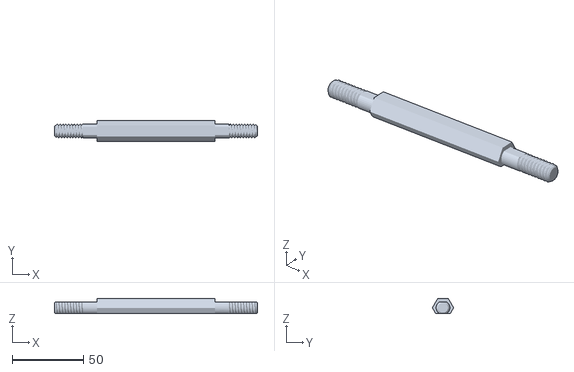
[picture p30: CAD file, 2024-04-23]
Hardware/CAD/screen-setup/Bar Printed v2.stl
142.8 x 15.0 x 10.5

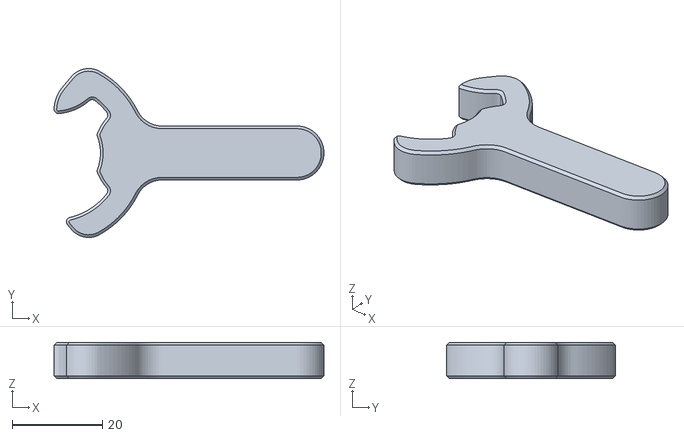
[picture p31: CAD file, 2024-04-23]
Hardware/CAD/screen-setup/Knob_Wrench.stl
59.9 x 37.5 x 8.00

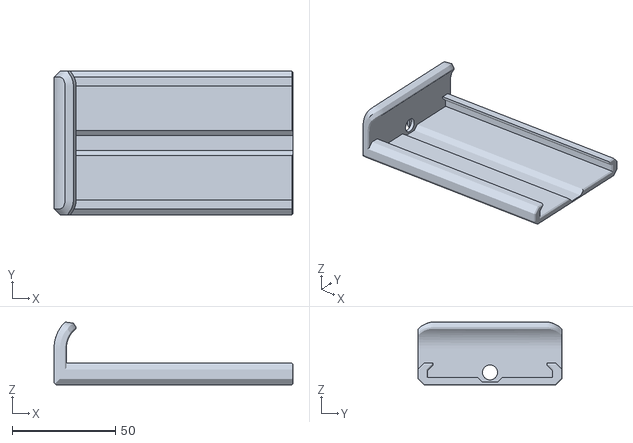
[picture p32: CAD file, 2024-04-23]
Hardware/CAD/screen-setup/TClamp L Thick Slider.stl
116.0 x 70.0 x 30.6

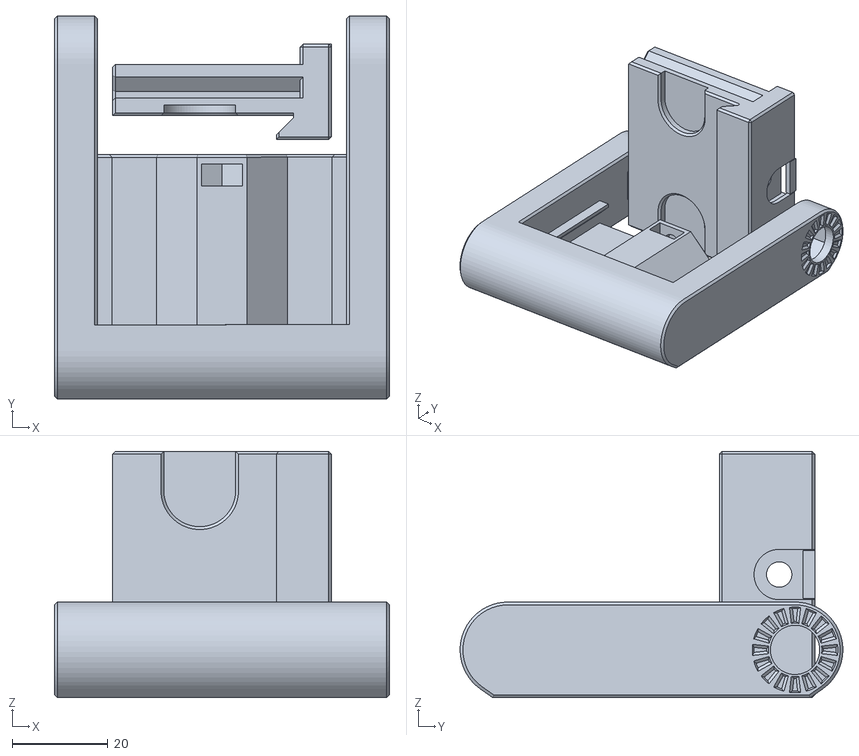
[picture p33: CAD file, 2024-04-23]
Hardware/CAD/screen-setup/Clamp Frame v2.stl
70.0 x 80.0 x 51.5

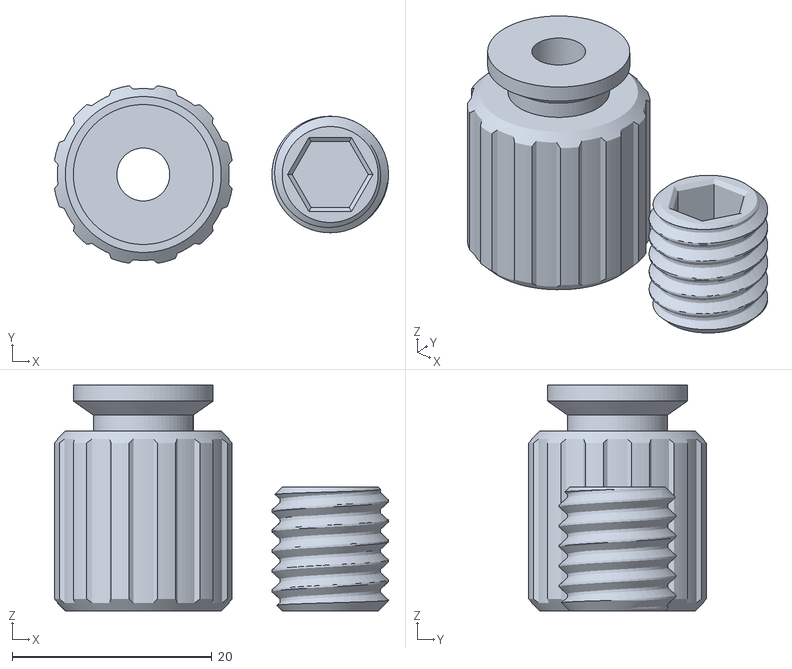
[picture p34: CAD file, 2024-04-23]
Hardware/CAD/screen-setup/Clamp Knob v1.stl
33.4 x 17.8 x 22.6

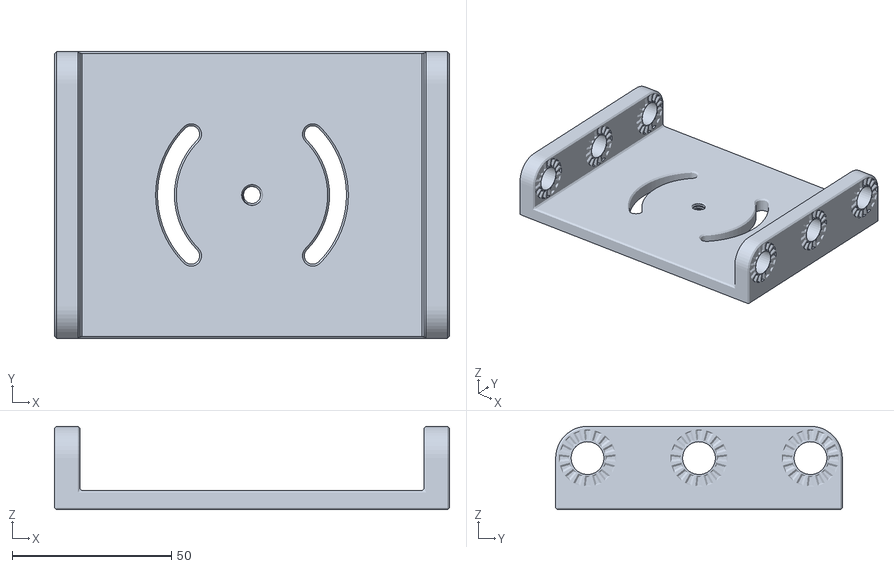
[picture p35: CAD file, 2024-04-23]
Hardware/CAD/screen-setup/Base Plate v1.stl
124.0 x 90.0 x 26.2

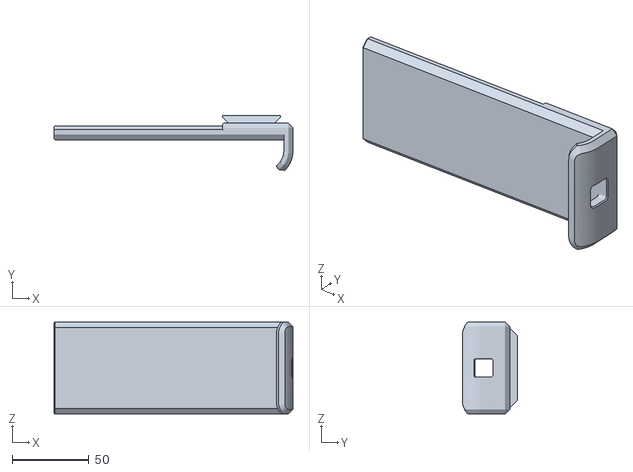
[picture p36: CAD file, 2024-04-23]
Hardware/CAD/screen-setup/TClamp L Thick Base.stl
156.0 x 35.8 x 60.0

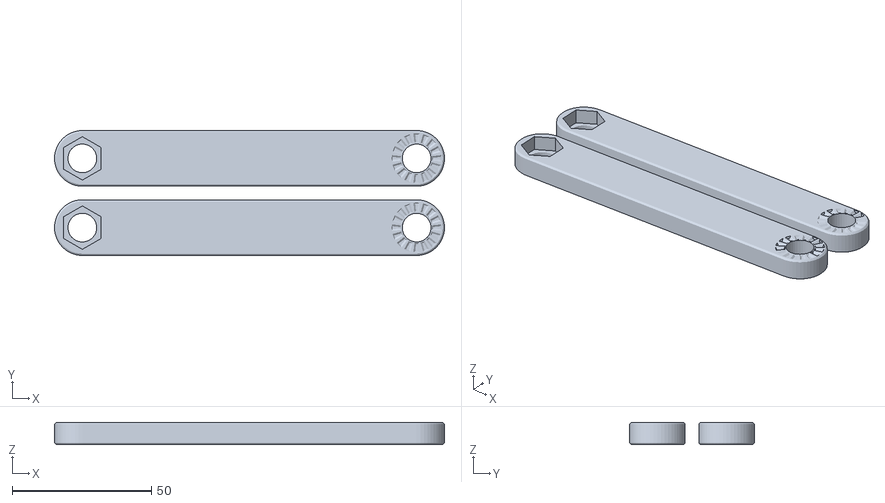
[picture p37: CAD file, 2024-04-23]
Hardware/CAD/screen-setup/Arm Last v1.stl
140.0 x 44.9 x 8.00

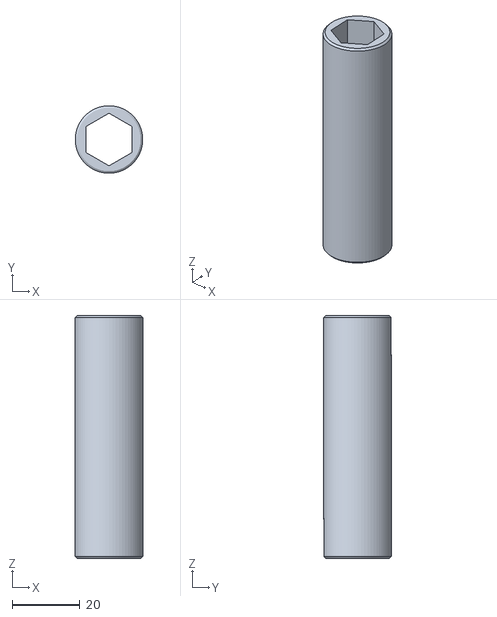
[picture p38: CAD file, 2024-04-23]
Hardware/CAD/screen-setup/Bar Sleeve.stl
20.0 x 20.0 x 72.0

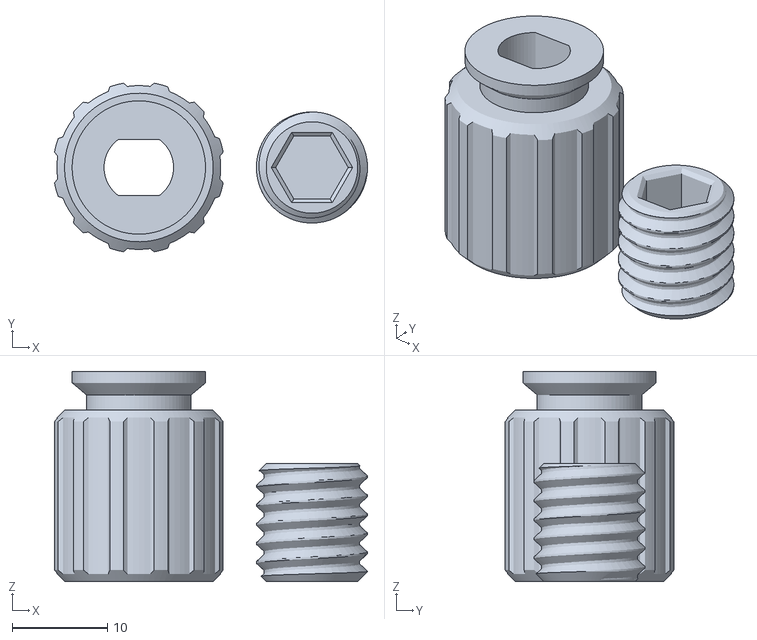
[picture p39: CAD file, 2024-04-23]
Hardware/CAD/screen-setup/TClamp Knob.stl
32.9 x 17.7 x 22.1

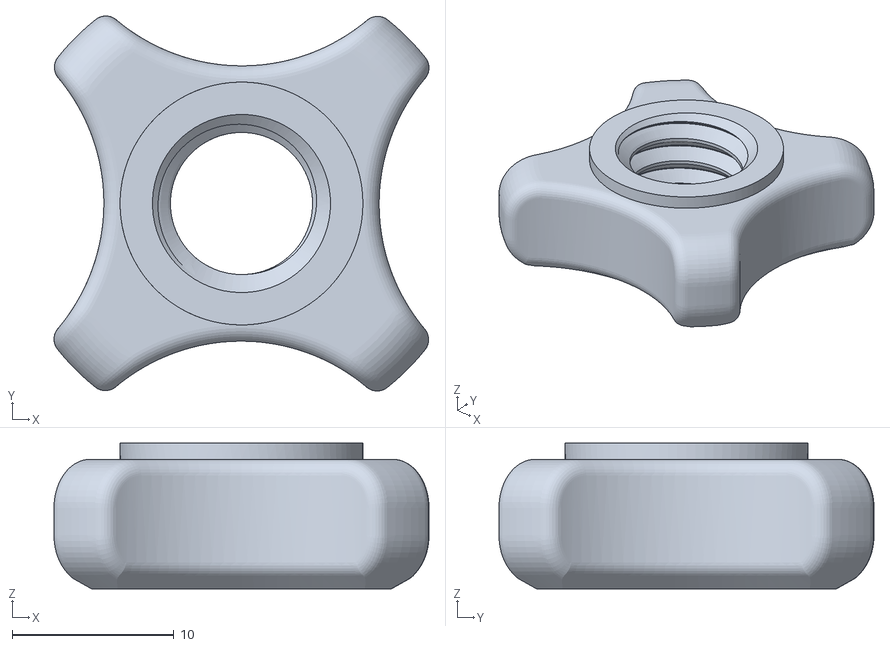
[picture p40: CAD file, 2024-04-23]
Hardware/CAD/screen-setup/Knob Threaded.stl
23.2 x 23.2 x 9.00

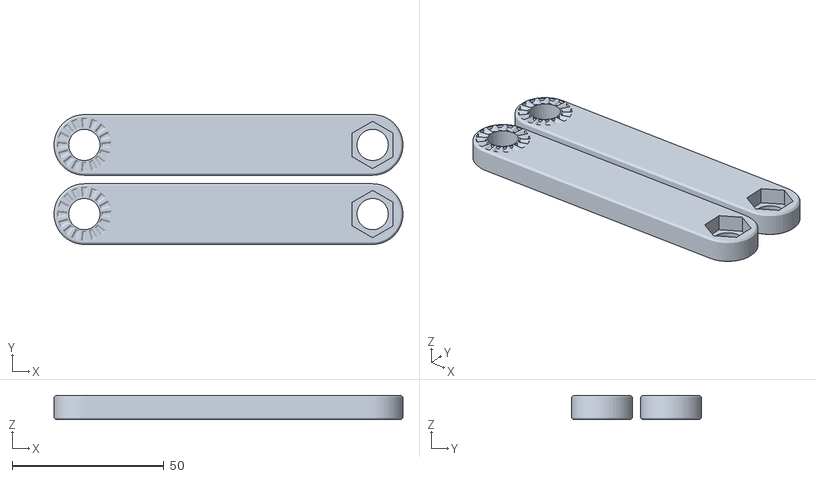
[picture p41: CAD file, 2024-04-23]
Hardware/CAD/screen-setup/Arm First v2.stl
115.0 x 42.8 x 8.00

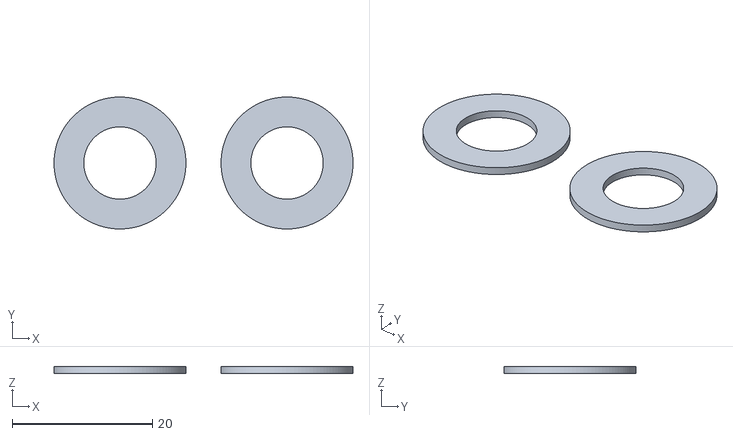
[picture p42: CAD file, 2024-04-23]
Hardware/CAD/screen-setup/Washer Friction v1.stl
42.6 x 18.8 x 1.00

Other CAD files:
Hardware/CAD/screen-setup/Washer Locking v1.stl
Hardware/CAD/screen-setup/TClamp L Bolt.stl
Hardware/CAD/screen-setup/Clamp Bolt v2.stl
Hardware/CAD/Cable_covers.f3d
Hardware/CAD/Circuit_Housing 3.f3d
Hardware/CAD/Instrumented_Platform_B 2.f3d
Hardware/CAD/Instrumented_Platform_T 2.f3d
Hardware/CAD/Peg_Ring.f3d
Hardware/CAD/Screen_Case.f3d
Hardware/CAD/Screen_Fixture.f3d
Hardware/CAD/Sensor_Housing.f3z
Hardware/CAD/Trocar_Mount 3.f3d
Hardware/CAD/screen-setup/Bolt Printed v2.stl

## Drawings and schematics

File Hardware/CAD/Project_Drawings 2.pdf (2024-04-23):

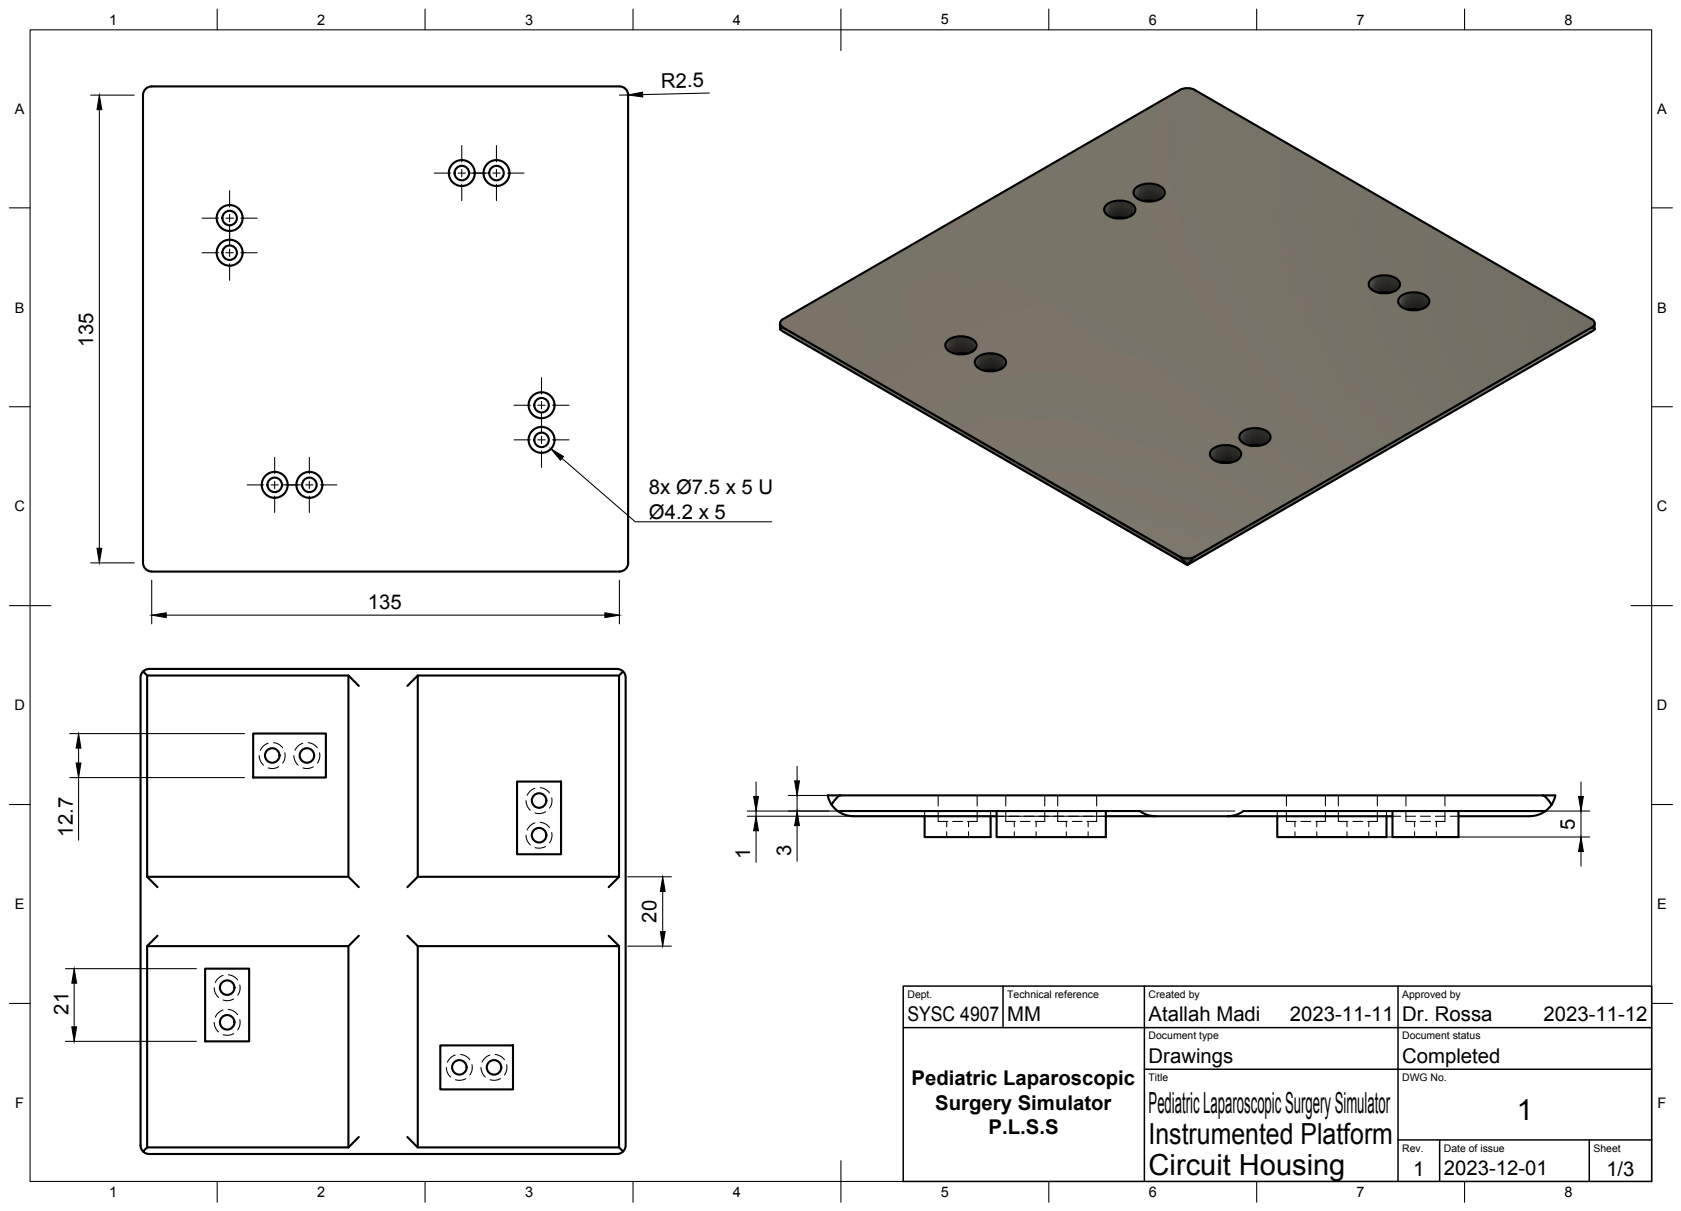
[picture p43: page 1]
Title; DWG No.; Rev.; Date of issue; Sheet; Circuit Housing; Instrumented Platform; Pediatric Laparoscopic Surgery Simulator

Dept. SYSC 4907 | Technical reference MM | Created by Atallah Madi 2023-11-11 | Approved by Dr. Rossa 2023-11-12

Document type Drawings | Document status Completed

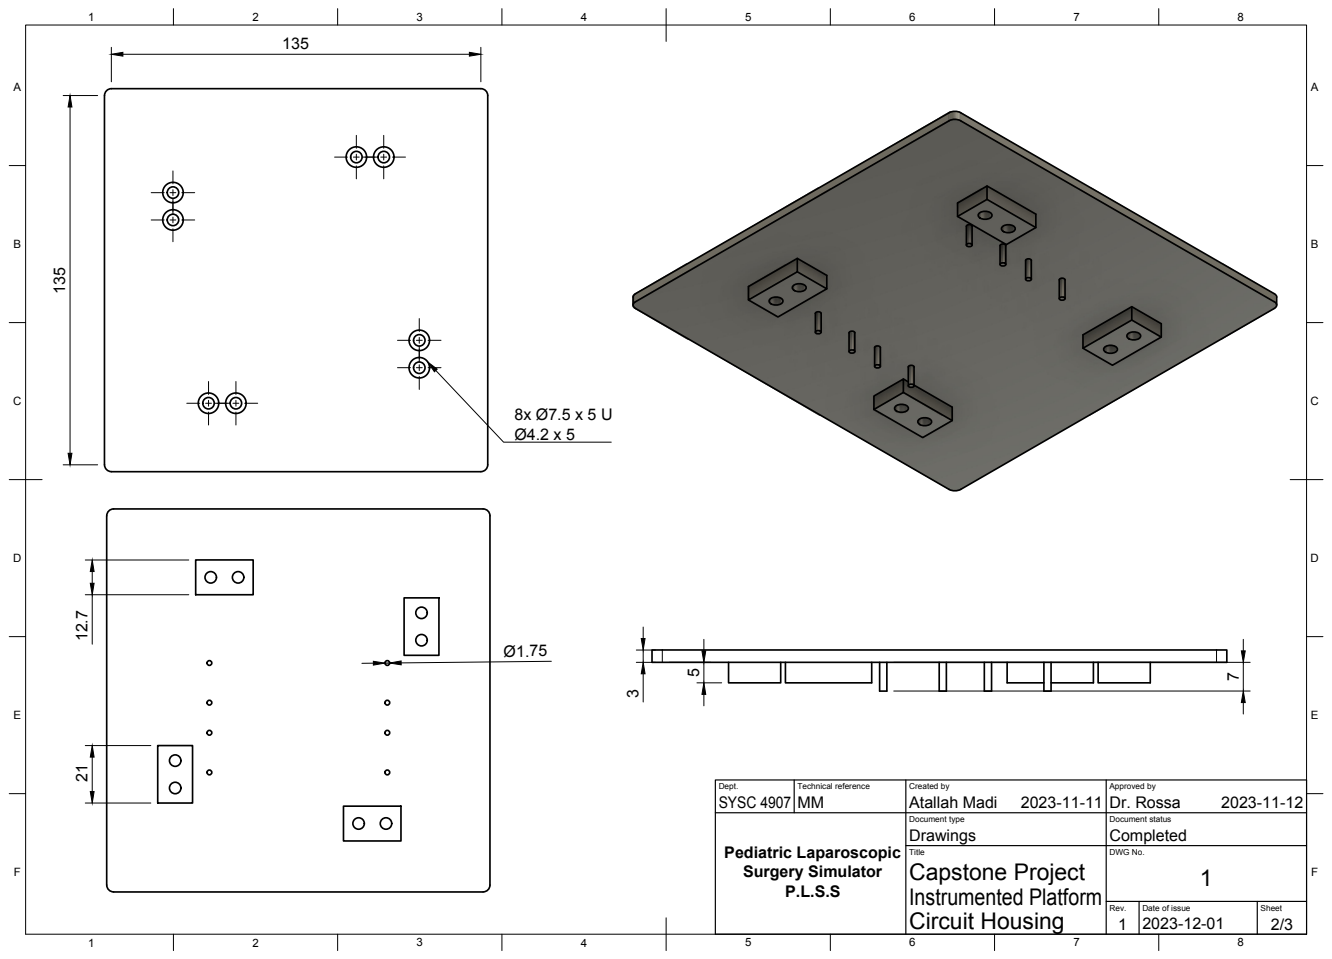
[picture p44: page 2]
Title; DWG No.; Circuit Housing; Capstone Project; SYSC 4907; Atallah Madi; Dr. Rossa 21 12.7 135; Pediatric Laparoscopic Surgery Simulator

Dept. | Technical reference | Created by 2023-11-11 | Approved by 2023-11-12

Document type Drawings | Document status Completed

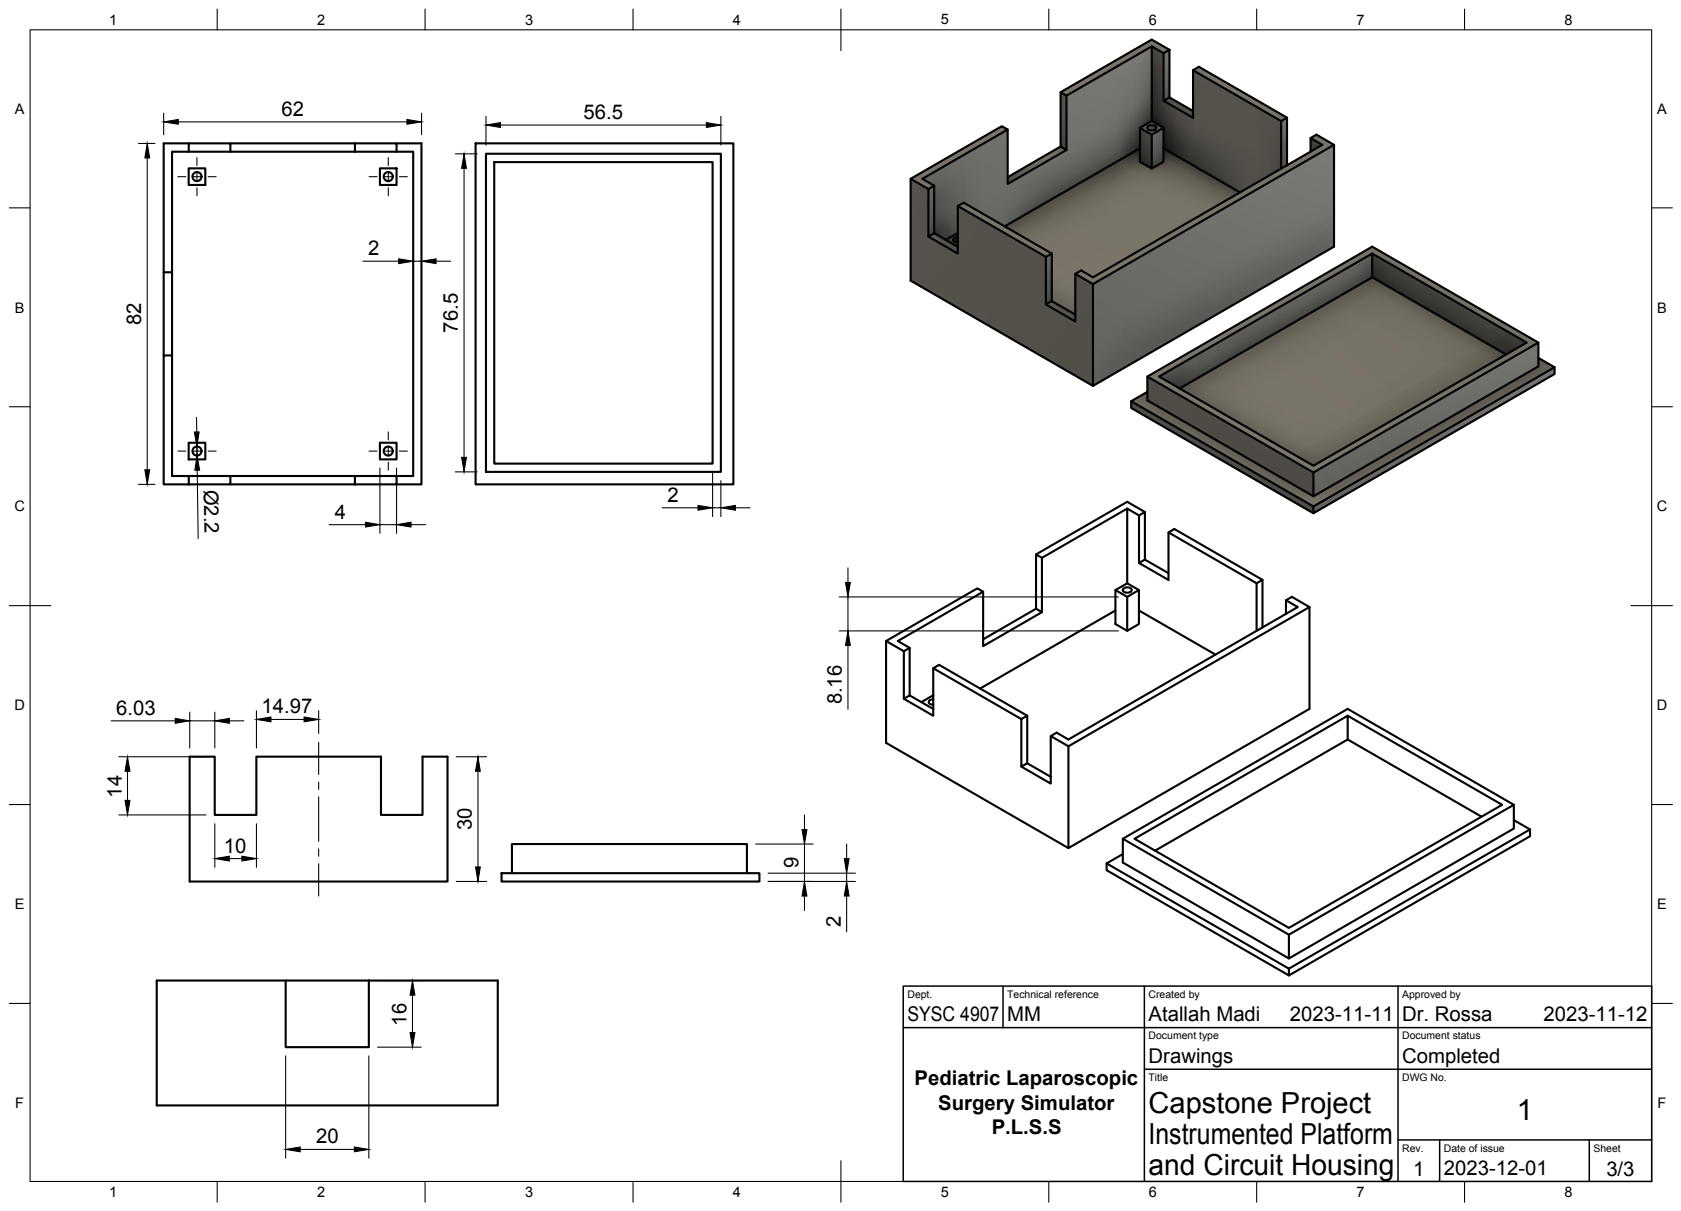
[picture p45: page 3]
Title; DWG No.; and Circuit Housing; Capstone Project; Pediatric Laparoscopic Surgery Simulator

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

Document type Drawings | Document status Completed

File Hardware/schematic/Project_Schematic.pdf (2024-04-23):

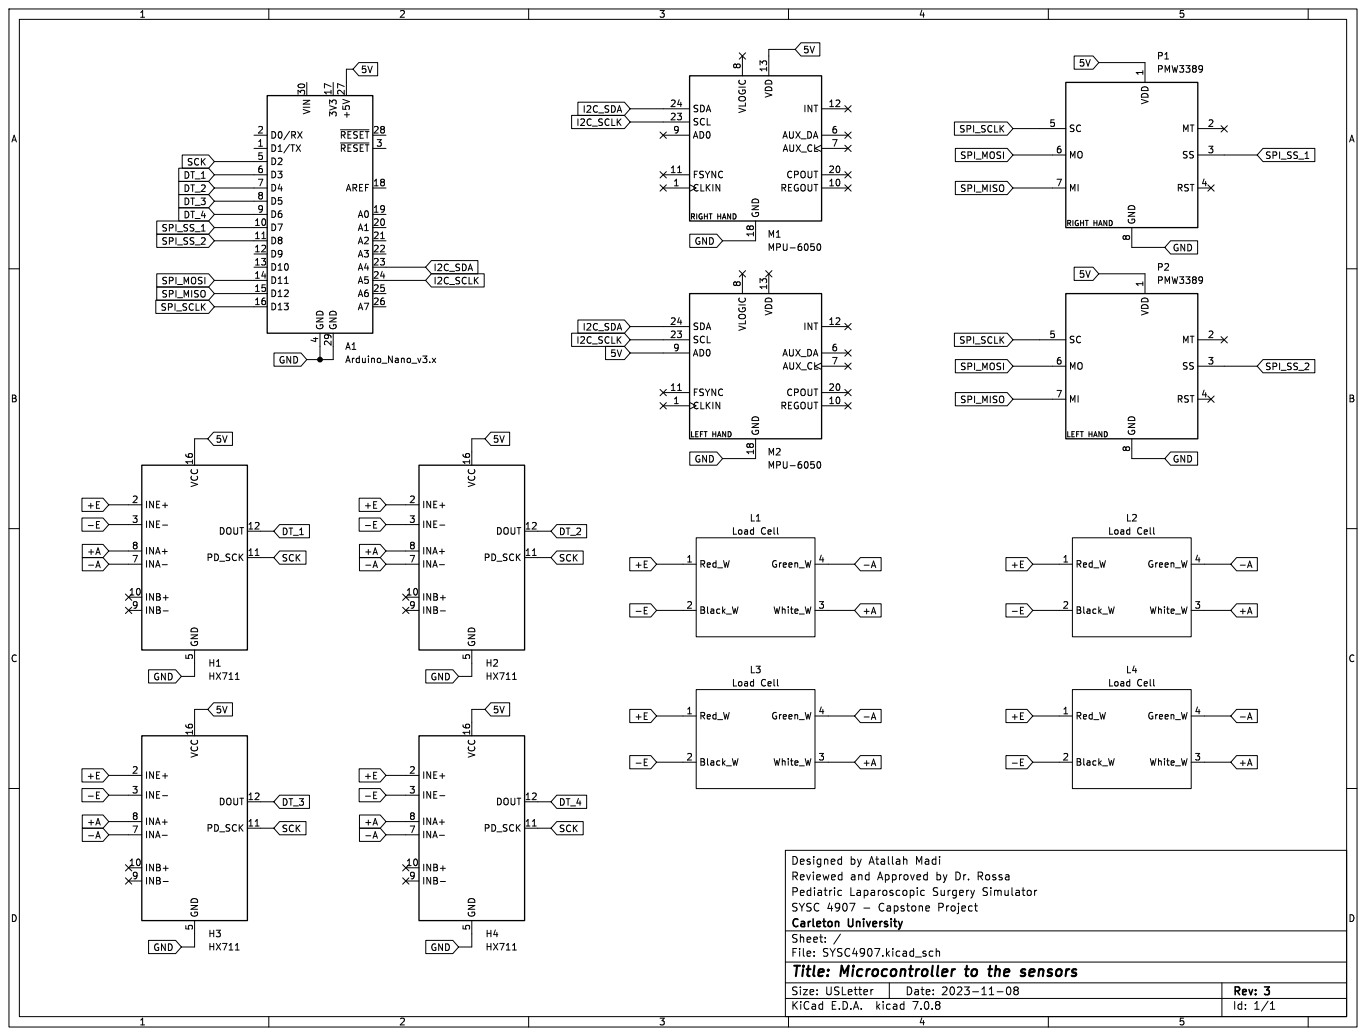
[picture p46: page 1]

8 P1PMW3389 RST 4 MO 6 MI 7 VDD

8 AD0 9 M1 MPU-6050 RST 4 MO 6 MI 7 VDD

1 MT 2 SS 3 SC 5 GND

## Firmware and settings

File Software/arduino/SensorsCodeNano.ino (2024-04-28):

/*********************************************************************************************
Author: Atallah Madi
Date: October 21th, 2023
Last edited: November 10th, 2023
Purpose: This code is used to read data from MPU6050, PMW3389, HX711 ADC and Load cells.
         The data is then sent to the computer via Serial. The data is then read by Python Application
         This code is for the Arduino Nano.
*********************************************************************************************/

// Libraries
// ~~~~~~~~~~~~~~~~~~~~~~~~~~~~~~~~~~~~~~~~~~~~~~~~~~~~~~~~~~~~~~~
#include <MPU6050_1.h> // Include the library for MPU6050 sensor
#include <MPU6050_2.h> // Include the library for MPU6050 sensor
#include <PMW3389.h>   // Include the library for PMW3389 sensor
#include <HX711.h>     // Include the HX711 library for force sensors
#include <Wire.h>      // Include the Wire library for I2C communication
#include <SPI.h>       // Include the SPI library for SPI communication
// ~~~~~~~~~~~~~~~~~~~~~~~~~~~~~~~~~~~~~~~~~~~~~~~~~~~~~~~~~~~~~~~

/* Constants declaration, and pins definition */
// ~~~~~~~~~~~~~~~~~~~~~~~~~~~~~~~~~~~~~~~~~~~~~~~~~~~~~~~~~~~~~~~
// I2C pins, digital pins
#define SCL_PIN 19 // A5
#define SDA_PIN 18 // A4

// SPI pins, digital pins
#define SCK_PIN 13  // D13
#define MISO_PIN 12 // D12
#define MOSI_PIN 11 // D11
#define SS_PIN_1 8  // D8
#define SS_PIN_2 7  // D7

// Force sensor pins, digital pins
#define FORCE_4_PIN 6   // D6
#define FORCE_3_PIN 5   // D5
#define FORCE_2_PIN 4   // D4
#define FORCE_1_PIN 3   // D3
#define FORCE_CLK_PIN 2 // D2

const int SERIAL_BAUD_RATE = 31250;

const float SCALE_FACTOR = 830;              // this value is obtained by calibrating the scale with known weights
const float SCALE_CONV_FACTOR = 0.009806652; // Newtons = Grams * 0.009806652
// ~~~~~~~~~~~~~~~~~~~~~~~~~~~~~~~~~~~~~~~~~~~~~~~~~~~~~~~~~~~~~~~

/* Initializing Libraries */
// ~~~~~~~~~~~~~~~~~~~~~~~~~~~~~~~~~~~~~~~~~~~~~~~~~~~~~~~~~~~~~~~
HX711 scale1;
HX711 scale2;
HX711 scale3;
HX711 scale4;
PMW3389 sensor1;          // LEFT HAND
PMW3389 sensor2;          // RIGHT HAND
MPU6050 mpu6050_1(Wire);  // LEFT HAND
MPU60502 mpu6050_2(Wire); // RIGHT HAND
// ~~~~~~~~~~~~~~~~~~~~~~~~~~~~~~~~~~~~~~~~~~~~~~~~~~~~~~~~~~~~~~~

/* Variables declaration */
// ~~~~~~~~~~~~~~~~~~~~~~~~~~~~~~~~~~~~~~~~~~~~~~~~~~~~~~~~~~~~~~~
long timer = millis();              // timer for MPU6050
long prevTimeSinceStart = millis(); // timer for PMW3389

// Sensor variables
float xL = 0;
float yL = 0;
float zL = 0;

float xR = 0;
float yR = 0;
float zR = 0;

float force = 0;
int weight1 = 0;
int weight2 = 0;
int weight3 = 0;
int weight4 = 0;
bool allScalesNonZero;

float L_pitch = 0;
float L_yaw = 0;

float R_pitch = 0;
float R_yaw = 0;

float L_PMW_X = 0;
float L_PMW_X_vel = 0;
float L_PMW_X_acc = 0;
float L_PMW_Y = 0;
float L_PMW_Y_vel = 0;
float L_PMW_Y_acc = 0;

float R_PMW_X = 0;
float R_PMW_X_vel = 0;
float R_PMW_X_acc = 0;
float R_PMW_Y = 0;
float R_PMW_Y_vel = 0;
float R_PMW_Y_acc = 0;

float L_yawVel = 0;
float L_yawAcc = 0;
float L_pitchVel = 0;
float L_pitchAcc = 0;
float prev_L_yaw = 0;
float prev_L_yawVel = 0;
float prev_L_pitch = 0;
float prev_L_pitchVel = 0;

float R_yawVel = 0;
float R_yawAcc = 0;
float R_pitchVel = 0;
float R_pitchAcc = 0;
float prev_R_yaw = 0;
float prev_R_yawVel = 0;
float prev_R_pitch = 0;
float prev_R_pitchVel = 0;

float prev_L_PMW_X = 0;
float prev_L_PMW_Y = 0;
float prev_L_PMW_X_vel = 0;
float prev_L_PMW_Y_vel = 0;
float prev_R_PMW_X = 0;
float prev_R_PMW_Y = 0;
float prev_R_PMW_X_vel = 0;
float prev_R_PMW_Y_vel = 0;
// ~~~~~~~~~~~~~~~~~~~~~~~~~~~~~~~~~~~~~~~~~~~~~~~~~~~~~~~~~~~~~~~

/* Intializing Sensors */
// ~~~~~~~~~~~~~~~~~~~~~~~~~~~~~~~~~~~~~~~~~~~~~~~~~~~~~~~~~~~~~~~
void setup()
{
  Wire.begin();
  Serial.begin(SERIAL_BAUD_RATE);

  // MPU portion
  mpu6050_1.begin();
  mpu6050_1.calcGyroOffsets(true);
  mpu6050_2.begin();
  mpu6050_2.calcGyroOffsets(true);

  while (!Serial)
    ; // Wait for serial to initialize.

  sensor1.begin(SS_PIN_1, 16000); // to set CPI (Count per Inch), pass it as the
  sensor2.begin(SS_PIN_2, 16000); // second argument to the begin function

  // Force sensor portion
  scale1.begin(FORCE_1_PIN, FORCE_CLK_PIN);
  scale2.begin(FORCE_2_PIN, FORCE_CLK_PIN);
  scale3.begin(FORCE_3_PIN, FORCE_CLK_PIN);
  scale4.begin(FORCE_4_PIN, FORCE_CLK_PIN);

  scale1.set_scale(SCALE_FACTOR); // RAW_Reading/SCALE_FACTOR = grams
  scale2.set_scale(SCALE_FACTOR);
  scale3.set_scale(SCALE_FACTOR);
  scale4.set_scale(SCALE_FACTOR);

  scale1.tare(); // reset the scale to 0
  scale2.tare(); // sets current weight as to offset
  scale3.tare(); // RAW_Reading - OFFSET = 0
  scale4.tare();
}

/* Main Program */
// ~~~~~~~~~~~~~~~~~~~~~~~~~~~~~~~~~~~~~~~~~~~~~~~~~~~~~~~~~~~~~~~
void loop()
{
  unsigned long currentMillis = millis(); // current time for MPU6050 in milliseconds

  mpu6050_1.update(); // update MPU6050
  mpu6050_2.update(); // update MPU6050

  // Read data from sensors every 100 milliseconds
  if (currentMillis - timer > 100)
  {
    unsigned long timeSinceStart = millis();

    // MPU gets data from updates
    float L_yaw = mpu6050_2.getAngleY();
    float L_yawVel = 0;
    float L_yawAcc = 0;
    float L_pitch = mpu6050_2.getAngleX();
    float L_pitchVel = 0;
    float L_pitchAcc = 0;

    float R_yaw = mpu6050_1.getAngleY();
    float R_yawVel = 0;
    float R_yawAcc = 0;
    float R_pitch = mpu6050_1.getAngleX();
    float R_pitchVel = 0;
    float R_pitchAcc = 0;

    // Left MPU velocity and acceleration
    if (prev_L_yaw != 0)
    {
      L_yawVel = (L_yaw - prev_L_yaw) * 1000.00 / (timeSinceStart - prevTimeSinceStart); // deg/s
    }
    if (prev_L_pitch != 0)
    {
      L_pitchVel = (L_pitch - prev_L_pitch) * 1000.00 / (timeSinceStart - prevTimeSinceStart); // deg/s
    }

    // Accelerations
    if (prev_L_yawVel != 0)
    {
      L_yawAcc = (L_yawVel - prev_L_yawVel) * 1000.00 / (timeSinceStart - prevTimeSinceStart); // deg/s^2
    }
    if (prev_L_pitchVel != 0)
    {
      L_pitchAcc = (L_pitchVel - prev_L_pitchVel) * 1000.00 / (timeSinceStart - prevTimeSinceStart); // deg/s^2
    }

    // Right MPU velocity and acceleration
    if (prev_R_yaw != 0)
    {
      R_yawVel = (R_yaw - prev_R_yaw) * 1000.00 / (timeSinceStart - prevTimeSinceStart); // deg/s
    }
    if (prev_R_pitch != 0)
    {
      R_pitchVel = (R_pitch - prev_R_pitch) * 1000.00 / (timeSinceStart - prevTimeSinceStart); // deg/s
    }

    // Accelerations
    if (prev_R_yawVel != 0)
    {
      R_yawAcc = (R_yawVel - prev_R_yawVel) * 1000.00 / (timeSinceStart - prevTimeSinceStart); // deg/s^2
    }
    if (prev_R_pitchVel != 0)
    {
      R_pitchAcc = (R_pitchVel - prev_R_pitchVel) * 1000.00 / (timeSinceStart - prevTimeSinceStart); // deg/s^2
    }

    // Get data from PMW3389 sensors via readburst
    PMW3389_DATA data1 = sensor2.readBurst();
    PMW3389_DATA data2 = sensor1.readBurst();

    if (data1.isMotion || data1.isOnSurface)
    {
      L_PMW_X = ((data1.dx)) + L_PMW_X; // converts to 1mm since 16,000 CPI 16000=32767 in two's compliment so 32767=16,000=inch=25.4mm therefore 1290=1mmm.
      L_PMW_Y = ((data1.dy)) + L_PMW_Y; // Can measure 10cm on ruler and use that bit value to convert
    }
    if (data2.isMotion || data2.isOnSurface)
    {
      R_PMW_X = ((data2.dx)) + R_PMW_X; // converts to 1mm since 16,000 CPI 16000=32767 in two's compliment so 32767=16,000=inch=25.4mm therefore 1290=1mmm.
      R_PMW_Y = ((data2.dy)) + R_PMW_Y;
    }

    // Left PMW velocities
    if (prev_L_PMW_X != 0)
    {
      L_PMW_X_vel = (L_PMW_X - prev_L_PMW_X) / (timeSinceStart - prevTimeSinceStart); // units/s
    }
    if (prev_L_PMW_Y != 0)
    {
      L_PMW_Y_vel = (L_PMW_Y - prev_L_PMW_Y) / (timeSinceStart - prevTimeSinceStart); // units/s
    }

    // Left PMW accelerations
    if (prev_L_PMW_X_vel != 0)
    {
      L_PMW_X_acc = (L_PMW_X_vel - prev_L_PMW_X_vel) / (timeSinceStart - prevTimeSinceStart); // units/s^2
    }
    if (prev_L_PMW_Y_vel != 0)
    {
      L_PMW_Y_acc = (L_PMW_Y_vel - prev_L_PMW_Y_vel) / (timeSinceStart - prevTimeSinceStart); // units/s^2
    }

    // Right PMW velocities
    if (prev_R_PMW_X != 0)
    {
      R_PMW_X_vel = (R_PMW_X - prev_R_PMW_X) / (timeSinceStart - prevTimeSinceStart); // units/s
    }
    if (prev_R_PMW_Y != 0)
    {
      R_PMW_Y_vel = (R_PMW_Y - prev_R_PMW_Y) / (timeSinceStart - prevTimeSinceStart); // units/s
    }

    // Right PMW accelerations
    if (prev_R_PMW_X_vel != 0)
    {
      R_PMW_X_acc = (R_PMW_X_vel - prev_R_PMW_X_vel) / (timeSinceStart - prevTimeSinceStart); // units/s^2
    }
    if (prev_R_PMW_Y_vel != 0)
    {
      R_PMW_Y_acc = (R_PMW_Y_vel - prev_R_PMW_Y_vel) / (timeSinceStart - prevTimeSinceStart); // units/s^2
    }

    // If not in motion/on surface, reset acceleration value back to zero
    if (!(data1.isMotion || data1.isOnSurface))
    {
      L_PMW_X_acc = 0;
      L_PMW_Y_acc = 0;
      L_PMW_X_vel = 0;
      L_PMW_Y_vel = 0;
      L_PMW_X = 0;
      L_PMW_Y = 0;
    }
    if (!(data2.isMotion || data2.isOnSurface))
    {
      R_PMW_X_acc = 0;
      R_PMW_Y_acc = 0;
      R_PMW_X_vel = 0;
      R_PMW_Y_vel = 0;
      R_PMW_X = 0;
      R_PMW_Y = 0;
    }

    /* Force sensors readings */
    // ~~~~~~~~~~~~~~~~~~~~~~~~~~~~~~~~~~~~~~~~~~~~~~~~~~~~~~~~~~~~~~~
    // Force sensors readings (grams)
    if (scale1.is_ready() && scale2.is_ready() && scale3.is_ready() && scale4.is_ready())
    {
      weight1 = scale1.get_units();
      weight2 = scale2.get_units();
      weight3 = scale3.get_units();
      weight4 = scale4.get_units();
    }
  
    // Check if all scales are non-zero
    allScalesNonZero = (weight1 != 0) && (weight2 != 0) && (weight3 != 0) && (weight4 != 0);

    // Stability check: If any one scale is zero while others are not, ignore the readings
    if (allScalesNonZero) {
      // Calculate force in Newtons
      force = ((weight1 + weight2 + weight3 + weight4) * SCALE_CONV_FACTOR);
    } else { force = 0;}
    // ~~~~~~~~~~~~~~~~~~~~~~~~~~~~~~~~~~~~~~~~~~~~~~~~~~~~~~~~~~~~~~~

    /*
    Print sensor data from Serial into .txt file
    force = if -ve, then it is pushing force, if +ve, then it is pull force
    L_PMW_Y / R_PMW_Y = surge
    L_PMW_X / R_PMW_X = roll
    L_pitch / R_pitch = pitch
    L_yaw / R_yaw = yaw
    */
    // ~~~~~~~~~~~~~~~~~~~~~~~~~~~~~~~~~~~~~~~~~~~~~~~~~~~~~~~~~~~~~~~
    Serial.println(String(force) + "|" +
                   String(L_pitchAcc / 1000) + "|" + String(L_yawAcc / 1000) + "|" +
                   String(R_pitchAcc / 1000) + "|" + String(R_yawAcc / 1000) + "|" +
                   String(L_PMW_Y_acc) + "|" + String(L_PMW_X_acc) + "|" +
                   String(R_PMW_Y_acc) + "|" + String(R_PMW_X_acc) + "|" +
                   String(L_pitchVel) + "|" + String(L_yawVel) + "|" +
                   String(R_pitchVel) + "|" + String(R_yawVel) + "|" +
                   String(L_PMW_Y_vel) + "|" + String(L_PMW_X_vel) + "|" +
                   String(R_PMW_Y_vel) + "|" + String(R_PMW_X_vel) + "|" +
                   String(L_pitch) + "|" + String(L_yaw) + "|" +
                   String(R_pitch) + "|" + String(R_yaw) + "|" +
                   String(L_PMW_Y) + "|" + String(L_PMW_X) + "|" +
                   String(R_PMW_Y) + "|" + String(R_PMW_X) + "|" +
                   String(xR) + "|" + String(yR) + "|" + String(zR) + "|" +
                   String(xL) + "|" + String(yL) + "|" + String(zL) + "|" +
                   String(data1.isMotion && data1.isOnSurface) + "|" +
                   String(data2.isMotion && data2.isOnSurface));

    /* Save previous values */
    // ~~~~~~~~~~~~~~~~~~~~~~~~~~~~~~~~~~~~~~~~~~~~~~~~~~~~~~~~~~~~~~~
    prevTimeSinceStart = timeSinceStart;
    prev_L_yaw = L_yaw;
    prev_L_yawVel = L_yawVel;
    prev_L_pitch = L_pitch;
    prev_L_pitchVel = L_pitchVel;

    prev_R_yaw = R_yaw;
    prev_R_yawVel = R_yawVel;
    prev_R_pitch = R_pitch;
    prev_R_pitchVel = R_pitchVel;

    prev_L_PMW_X = L_PMW_X;
    prev_L_PMW_X_vel = L_PMW_X_vel;
    prev_L_PMW_Y = L_PMW_Y;
    prev_L_PMW_Y_vel = L_PMW_Y_vel;

    prev_R_PMW_X = R_PMW_X;
    prev_R_PMW_X_vel = R_PMW_X_vel;
    prev_R_PMW_Y = R_PMW_Y;
    prev_R_PMW_Y_vel = R_PMW_Y_vel;
  }
}

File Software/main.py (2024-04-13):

import os
import tkinter as tk
from tkinter import messagebox, filedialog, Toplevel
from tkinter import messagebox
import cv2
import imageio
from PIL import Image, ImageTk
import pandas as pd
import os
import numpy as np
import time
import serial
import threading
#import matplotlib.pyplot as plt
#from matplotlib.widgets import Slider, CheckButtons
from cleaning_sensor_data import SensorDataCleaner
from seg_data_to_subtasks import DataSegmentation
from user_task1_evaluation_Testing import Task1PerformanceAnalyzer
from user_task2_evaluation_Testing import Task2PerformanceAnalyzer
from user_task3_evaluation_Testing import Task3PerformanceAnalyzer
from plot_user_aligned_subtask1 import DataPlotter1
from plot_user_aligned_subtask2 import DataPlotter2
from plot_user_aligned_subtask3 import DataPlotter3
# from show_feedback_video import VideoPlayer
from itertools import cycle
from video_feedback_task1_Testing import Task1VideoPlayFeedback
from video_feedback_task2 import Task2VideoPlayFeedback
from video_feedback_task3 import Task3VideoPlayFeedback
from video_playback import VideoPlayerApp
from task1_written_feedback import check_signals_in_column1
from plot_main import plot_all_data
import warnings
from pygame import mixer


warnings.filterwarnings('ignore')

if not os.path.exists("Task 1 Feedback clips") and not os.path.exists("Task 2 Feedback clips") \
        and not os.path.exists("Task 3 Feedback clips"):
    os.mkdir("Task 1 Feedback clips")
    os.mkdir("Task 2 Feedback clips")
    os.mkdir("Task 3 Feedback clips")
    print("Folders Created")
else:
    # messagebox.showwarning(title="Warning", message="Folders Already Exist!")
    pass


class Application(tk.Tk):
    def __init__(self):
        super().__init__()
        self.title('Video Application')

        # Get the screen width and height
        self.screen_width = self.winfo_screenwidth()
        self.screen_height = self.winfo_screenheight()

        # Set the window size to the maximum screen size
        self.geometry(f'{self.screen_width}x{self.screen_height}')
        self.resizable(False, False)
        self.configure(bg='black')
        self.video_name = "LapSim1.mkv"
        self.video = imageio.get_reader(self.video_name)
        self.canvas = tk.Canvas(self, width=self.screen_width, height=self.screen_height)
        self.bind('<ButtonPress-1>', self.mouse_down)
        self.bind('<ButtonRelease-1>', self.mouse_up)
        self.bind('<B1-Motion>', self.mouse_drag)
        # First, create the shadow with an offset (e.g., 2 pixels to the right and down)
        self.shadow_offset_x = 3
        self.shadow_offset_y = 3
        self.shadow_color = 'black'
        self.welcome_text = self.canvas.create_text(self.screen_width/2 + 20, self.screen_height/3 + 30, text='Welcome', font=('MS Sans Serif', 80), fill='black', tags=("overlay", "text",))
        #self.welcome_shadow = self.canvas.create_text(self.screen_width/2 + self.shadow_offset_x, self.screen_height/3 + self.shadow_offset_y,text="Welcome",font=('MS Sans Serif', 100), fill=self.shadow_color, tags=("shadow",))
        #self.rect = self.canvas.create_rectangle(self.screen_width/2 + 400, 700, self.screen_height/3 + 100, 100, fill="black")
        self.current_user = "guest"
        self.back_button = None
        self.buttons = []
        self.base_directory = r"C:\Users\hudasheikh\Desktop\Pediatric-Laparoscopic-Surgery-Simulator-main\myLapSim\UserData"
        # Initialize the cycle of images
        self.image_paths = ["Slide2.png", "Slide3.png", "Slide4.png", "Slide5.png", "Slide6.png", "Slide7.png", "Slide8.png", "Slide9.png"]
        self.load_video()
        self.start_menu()
        mixer.init()
        self.canvas.pack()


    def play_audio(self, audio_file):
        mixer.music.load(audio_file)
        mixer.music.play()

    def stop_audio(self):
        mixer.music.stop()
    def create_user_folder(self, username):
        # Sanitize the username to prevent any invalid characters for folder names
        # This is important for security and compatibility of folder names
        safe_username = ''.join(c for c in username if c.isalnum() or c in (' ', '_')).rstrip()

        # Create the full path for the user's folder
        user_folder_path = os.path.join(self.base_directory, safe_username)

        # Check if the folder already exists, and if not, create it
        if not os.path.exists(user_folder_path):
            os.makedirs(user_folder_path)
            print(f"Folder created for user {safe_username} at {user_folder_path}")
        else:
            print(f"Folder already exists for user {safe_username} at {user_folder_path}")

        return user_folder_path
    def set_current_user(self, username):
        self.current_user = username
        user_folder = self.create_user_folder(self.current_user)

    def mouse_down(self, event):
        self.x, self.y = event.x, event.y

    def mouse_up(self, event):
        self.x, self.y = None, None

    def mouse_drag(self, event):
        if self.x and self.y:
            deltax = event.x - self.x
            deltay = event.y - self.y
            x0 = self.winfo_x() + deltax
            y0 = self.winfo_y() + deltay
            self.geometry(f"+{x0}+{y0}")

    def load_video(self):
        self.after(0, self.stream())

    def update_frame(self, frame_iterator):
        try:
            image = next(frame_iterator)
            resized_image = Image.fromarray(image).resize((self.winfo_screenwidth(), self.winfo_screenheight()),Image.Resampling.LANCZOS)  # Use the screen dimensions
            frame_image = ImageTk.PhotoImage(image=resized_image)
            if hasattr(self, 'canvas_image_id'):
                # Update the existing image object
                self.canvas.itemconfig(self.canvas_image_id, image=frame_image)
            else:
                # Create a new canvas image object and keep its ID
                self.canvas_image_id = self.canvas.create_image(
                    0, 0, anchor='nw', image=frame_image, tags=("video_frame",)
                )
                # Send this image to the back, so buttons/text stay on top
                self.canvas.tag_lower('video_frame')

            # Keep a reference to the image to prevent garbage-collection
            self.canvas.image = frame_image

            # Send this image to the back, so buttons/text stay on top
            self.canvas.tag_lower('video_frame')
            self.canvas.tag_raise('overlay')
            self.canvas.update_idletasks()

            # Schedule the next frame update
            self.after(33, self.update_frame, frame_iterator)  # For ~30fps, adjust as needed
        except StopIteration:
            # Handle the end of the video stream
            self.canvas.delete(self.canvas_image_id)  # Remove the video frame
            self.start_menu()  # Call start_menu or handle the video ending
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

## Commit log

2024-04-23 added HW, Docs, and readme
    [Arm First v2.stl, Arm Last v1.stl, Bar Printed v2.stl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]
2024-04-28 added Arduino files
